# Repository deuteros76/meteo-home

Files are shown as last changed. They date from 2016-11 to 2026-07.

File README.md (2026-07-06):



# meteo-home
MeteoHome was born as a weather station project using a NodeMCU ESP8266 devboard with DHT22 and BMP180 sensors. Now, the concept has changed and the board (currently a Wemos D1 Lite) and the source are being redesigned to allow the use of different type of sensors. One of the main features of MeteoHome is the configuration using a captive web portal and the use of MQTT to send the information to a server. Additionally, it has been designed to be connected to a machine running Home Assistant. In this case, this software could be used to show the current status of the sensors and display graphs.

## Features
- configuration of WiFi network and MQTT through a web portal 
- Deep sleep mode included for being powered by battery 
- Temperature, humidity, air pressure and air quality measurements depending on the sensors plugged to the board ( currently DHT22, BMP180, SGP30 or AHT20)
- Support for analog sensors (moisture, proximity) with configurable value mapping
- Enhanced captive portal with improved UI and grouped settings panels
- Possibility of being used with Home Assistant

### Supported Sensors
MeteoHome supports multiple sensor types that can be used simultaneously:

- DHT22: Temperature (°C) and humidity (%) measurements
- BMP180: Temperature (°C) and atmospheric pressure (Pa)
- SGP30: Air quality monitoring with CO2 (ppm) and VOC (ppb) measurements
- AHT20: High-precision temperature (°C) and humidity (%) readings
- Analog Sensors: Configurable for moisture (%) or proximity (mm) measurements through A0 pin

### LED Indicators
The board includes three status LEDs. These LEDs provide visual feedback during boot sequence and runtime operation:

During boot:

- All LEDs flash once during initial power-up
- Green LED indicates successful boot and connection

During operation with SGP30 air quality monitoring:

- Green LED: Indicates good air quality (CO2 < 600 ppm)
- Yellow LED: Indicates moderate air quality (CO2 600-800 ppm)
- Red LED: Indicates poor air quality (CO2 > 800 ppm)

## Future
The idea is to continue the development of both hardware and software. Currently the MCU is a Wemos D1 Lite but the plan is to extend the possibilities including an ESP32 or a Raspberry Pi Pico, At the same time, the software will accept more sensors and will be adapted to the new hardware.

- Integration of light sensor
- ~~Integration of ATH20 sensor~~
- Adoption of a new MCU (ESP32 or Raspberry Pi Pico)
- Hardware redesign for the new MCU
- Development of software for the new board 

## Requirements
- PlatformIO IDE (used to build, test and check quality of code)
- Additional libraries: WiFiManager, Arduino Json, PubSubClient, DHT, Adafruit BMP085 and Adafruit AHTX0 (see platformio.ini)
- A computer running MQTT
- [Optional] A computer running Home Assistant

## Building the software

To build the software PlatformIO is needed. There are two options, the first one is to use the IDE and the second, covered here, is to use the pio command:

```shell
pio run --environment d1_mini_lite
```

## Hardware

The hardware has been designed in Kicad. All the source files are available under the Kicad directory of this repository.

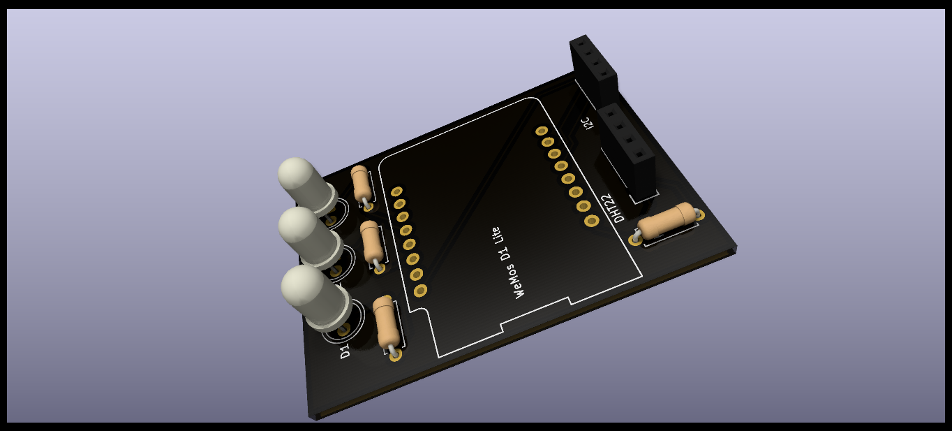
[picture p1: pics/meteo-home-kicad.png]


### Hardware components
- Wemos D1 Mini Lite (the board is designed to use this microcontroller)
- One or more sensors (DHT22, BMP180, SGP-30)
- Analog sensors (moisture, proximity sensors connected to A0 pin)
- Wires, tools...

Below the current BOM is shown. There are no sensors included, as the idea is to plug any of the supported and are not considered part of the hardware design:

|#  |Reference|Qty|Value |LibPart |Footprint|
|---|---|---|---|---|----|
|1  |A1 |1  |Analog Sensor |Connector:Conn_01x03_Socket |Connector_PinSocket_2.54mm:PinSocket_1x03_P2.54mm_Vertical|
|2  |D1 |1  |Red |meteo-home-rescue:LED-meteo-home-rescue-co2-detector-rescue |LED_THT:LED_D3.0mm|
|3  |D2 |1  |Yellow |meteo-home-rescue:LED-meteo-home-rescue-co2-detector-rescue |LED_THT:LED_D3.0mm|
|4  |D3 |1  |Green |meteo-home-rescue:LED-meteo-home-rescue-co2-detector-rescue |LED_THT:LED_D3.0mm|
|5  |DHT22 |1  |DHT22_Temperature_Humidity|meteo-home-rescue:DHT22_Temperature_Humidity-sensors-meteo-home-rescue-co2-detector-rescue|Sensors:DHT22_Temperature_Humidity|
|6  |I2C1 |1  |I2C 1 |Connector:Conn_01x04_Socket |Connector_PinSocket_2.54mm:PinSocket_1x04_P2.54mm_Vertical|
|7  |I2C2 |1  |I2C 2 |Connector:Conn_01x04_Socket |Connector_PinSocket_2.54mm:PinSocket_1x04_P2.54mm_Vertical|
|8  |I2C3 |1  |I2C 3 |Connector:Conn_01x04_Socket |Connector_PinSocket_1.00mm:PinSocket_1x04_P1.00mm_Vertical|
|9  |I2C4 |1  |I2C 4 |Connector:Conn_01x04_Socket |Connector_PinSocket_1.00mm:PinSocket_1x04_P1.00mm_Vertical|
|10 |J1 |1  |S 4 |Connector:Conn_01x04_Socket |Connector_PinSocket_2.54mm:PinSocket_1x04_P2.54mm_Vertical|
|11 |MCU1 |1  |WeMos_D1_mini |meteo-home-rescue:WeMos_D1_mini-wemos_mini-meteo-home-rescue-co2-detector-rescue|Module:WEMOS_D1_mini_light|
|12 |PWR1 |1  |Power connector |Connector:Conn_01x02_Socket |Connector_Molex:Molex_SL_171971-0002_1x02_P2.54mm_Vertical|
|13 |R1, R2 |2  |160 |meteo-home-rescue:R-meteo-home-rescue-co2-detector-rescue  |Resistor_THT:R_Axial_DIN0204_L3.6mm_D1.6mm_P5.08mm_Horizontal|
|14 |R3 |1  |90 |meteo-home-rescue:R-meteo-home-rescue-co2-detector-rescue  |Resistor_THT:R_Axial_DIN0204_L3.6mm_D1.6mm_P5.08mm_Horizontal|
|15 |R4 |1  |10K |meteo-home-rescue:R-meteo-home-rescue-co2-detector-rescue  |Resistor_THT:R_Axial_DIN0204_L3.6mm_D1.6mm_P5.08mm_Horizontal|
|16 |Tx1 |1  |Rx |Connector:Conn_01x02_Socket |Connector_PinSocket_2.54mm:PinSocket_1x02_P2.54mm_Vertical|

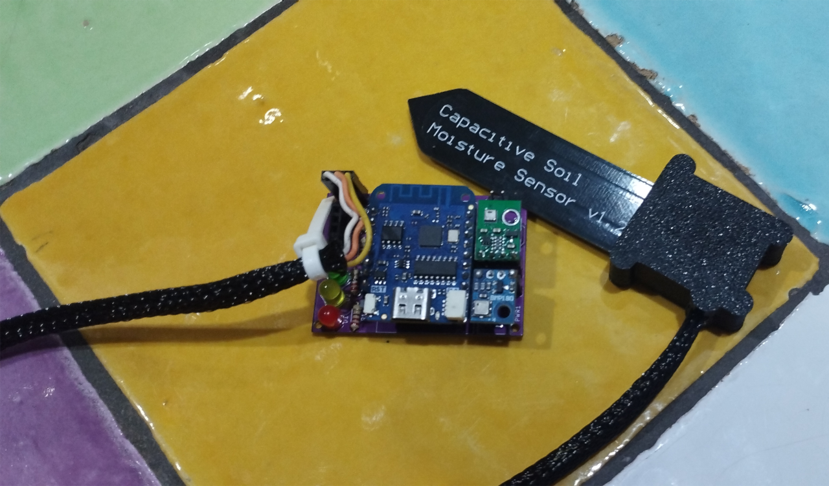
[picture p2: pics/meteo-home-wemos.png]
Real hardware
 

## Configuring a meteo-home device
After uploading the sketch and the first execution the device will run as an Access Point. Check the available networks for you computer and connect with "meteo-home". After that, point your browser to http://192.168.4.1 and the captive portal will be displayed. 

> **Note:** on some Android phones, the system's captive-portal-login popup can show a stale or incomplete cached version of the page (e.g. missing the "Network settings"/"MQTT Server settings"/"Device parameters" fields on the "Configure WiFi" page). If that happens, open a regular browser (Chrome, Firefox, etc.) and navigate to http://192.168.4.1 manually instead of using the auto-launched popup.

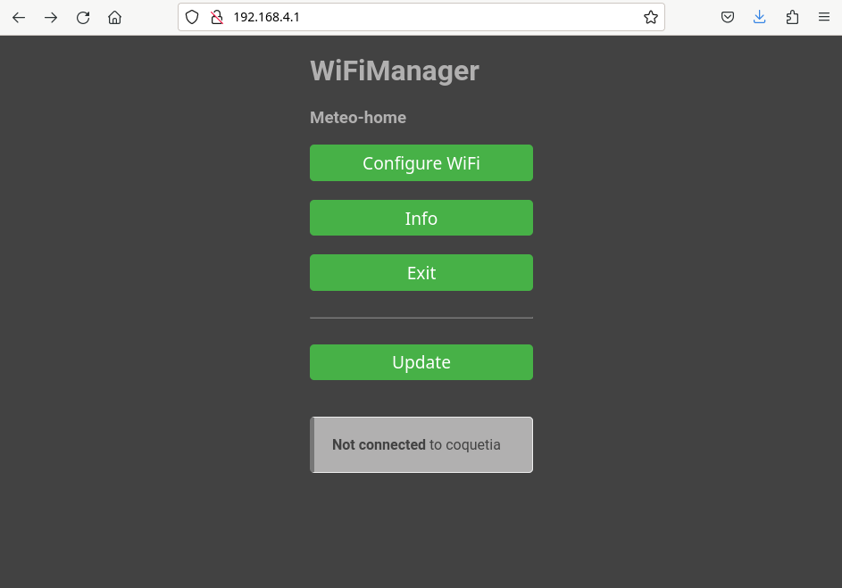
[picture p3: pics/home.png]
Home
 

Choose the first option ("Configure WiFi") and select your home WiFi network from the list of detected APs and introduce its password. 

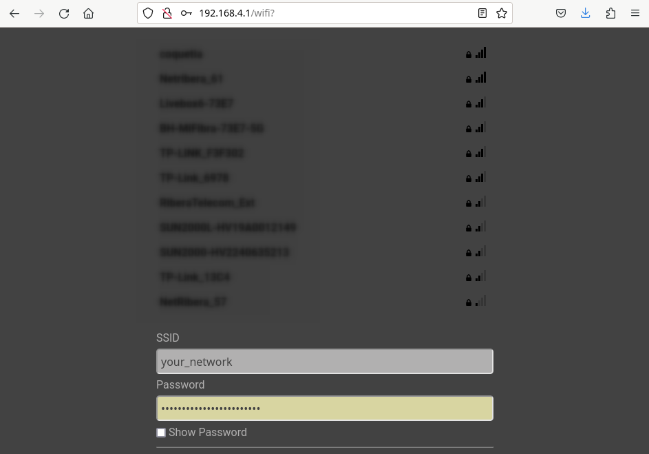
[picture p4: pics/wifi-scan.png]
Available networks
 

Now you have to configure your network settings. Below, the fields related to your MQTT server should be introduced. Then, in the "Device parameters" section, it is required to introduce a word identifying your device (you can use a name or the location where it will be installed). This value will be used to create the topics where the data will be sent through MQTT. 

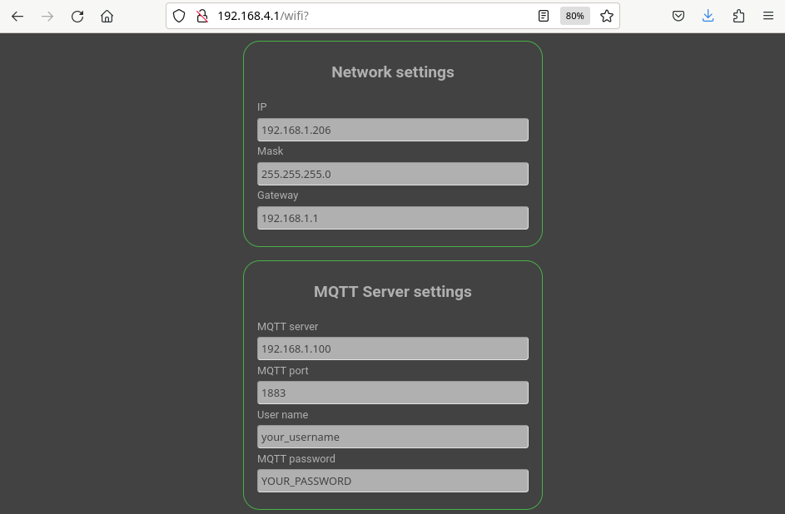
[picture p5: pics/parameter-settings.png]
Settings
 

The device supports analog sensors connected to the A0 pin. Through the captive portal, you can:

- Enable/disable analog sensor reading
- Select sensor class (moisture or proximity)
- Configure value mapping between raw analog readings (0-1024) to percentage (0-100%)
- Set minimum and maximum thresholds for the mapping function

Settings 

The improved captive portal now features:

- Grouped settings panels for better organization
- Dynamic show/hide of configuration options
- Real-time value preview using range sliders
- Enhanced visual styling and layout

## Remote reconfiguration

Once configured, a MeteoHome device can be reconfigured without physical access by
publishing an MQTT command. Only device/sensor parameters can be changed (not network or
MQTT credentials, which still require deleting `config.json` and going through the portal
again).

Each device has a secret 32-character token (`config_token`), generated automatically. On a
new device it is shown on the captive portal page, next to the device name. On a device
updated from a firmware version prior to this feature, the token is generated on the first
boot after the update and printed once over Serial (9600 baud) — check it before it's lost,
or delete `config.json` to go through the portal again and see it there.

To reconfigure, publish a JSON with `retain=true` to `meteohome/<device>/config/set`,
including the token and only the fields you want to change:

```shell
mosquitto_pub -h <broker> -t 'meteohome/attic/config/set' -r \
  -m '{"token":"<config_token>","sleep_minutes":10,"device_name":"attic"}'
```

Accepted fields: `device_name`, `use_sleep_mode`, `sleep_minutes` (1-60),
`use_analog_sensor`, `sensor_class`, `use_arduino_map_function`, `analog_min_value` and
`analog_max_value` (0-1024, with `analog_min_value < analog_max_value`).

The device responds on `meteohome/<device>/config/result` (not retained):

- `{"status":"applied","fields":[...]}` — change applied; the device restarts.
- `{"status":"error","reason":"invalid_token"}` — token missing or incorrect.
- `{"status":"error","reason":"invalid_payload"}` — malformed JSON.
- `{"status":"error","reason":"invalid_field:<name>"}` — a field is out of range or of the
  wrong type; no change is applied (transactional validation).

After processing the command (whether successful or not), the device clears the retained
message on `config/set` so it isn't reprocessed on the next reconnection.

In addition, on every connection to the broker the device publishes its current
configuration (without the token) as retained on `meteohome/<device>/config/state`:

```json
{
  "device_name": "attic",
  "use_sleep_mode": true,
  "sleep_minutes": 15,
  "use_analog_sensor": false,
  "sensor_class": "moisture",
  "use_arduino_map_function": true,
  "analog_min_value": 0,
  "analog_max_value": 1024
}
```

This topic makes it possible to build a form (for example, in Home Assistant) that
auto-fills with the device's real values before sending a change.

### Remote reconfiguration page

`tools/remote-config.html` is a self-contained page (HTML + JS, no backend or external
dependencies) that reads a device's state and applies changes without hand-crafting JSON.
Open it directly as a local file in your browser (double-click or `file://`).

**Prerequisite (one-time, on your broker):** enable a WebSocket listener. In Mosquitto, add
to the configuration:

```
listener 9001
protocol websockets
```

and restart the service. Without this, the page won't be able to connect.

**Usage:**
1. Open `tools/remote-config.html` in your browser.
2. Under "Broker connection", enter your broker's host and WebSocket port (the `9001` from
   the example above), and the MQTT username/password if your broker requires them. Click
   "Connect".
3. Under "Device", enter the device's `device_name` and its token, and click "Read current
   state" — the form will fill in with the device's real values.
4. Edit whichever fields you want to change and click "Apply changes". The device will
   apply the change (or return an error) and the result will appear in the "Result"
   section.

Connection details and each device's token are saved in the browser's `localStorage` where
you open the page, so you don't have to re-enter them every time — the same level of trust
you already assume by storing those same credentials elsewhere (e.g. Home Assistant). If you
expose the broker's WebSocket listener beyond your local network, do so at your own security
discretion; this page adds no extra protection on top of the existing token.

## Using MeteoHome with Home Assistant
A MeteoHome device publishes the data it collects to a MQTT broker. The topics used follow the specifications made by Home Assistant project and it is possible to use this software to store and use MeteoHome produced data. When a MeteoHome board is connected to a power source, it sends Home Assisant autodiscovery messages making it available through the MQTT integration.

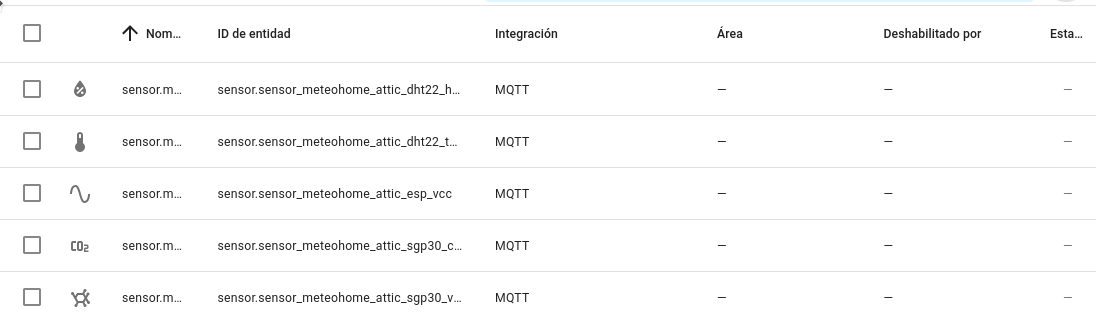
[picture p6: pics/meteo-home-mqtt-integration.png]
Home Assistant MQTT integration
 

If Home Assistant is not your preferred option, any other software that includes a MQTT broker could be used to obtain the data. To get the data, the software should be configured to subscribe to the appropriate topics. As an example the following topics are availabe if a DHT22 and SGP-30 sensors are plugged to a board configured with "attic" as topic prefix:

| Sensor  | Topic  | | | |
|---|---|---|---|---|
| DHT22  | attic/DHT22/temperature  | DHT22 temperature value  | | |
| DHT22  | attic/DHT22/humidity  | DHT22 humidity value  | | |
| DHT22  | attic/DHT22/heatindex  | DHT22 heat index value  | | |
| SGP30  | attic/SGP30/co2  | SGP30 CO2 ppp  | | |
| SGP30  | attic/SGP30/voc  | SGP30 air quality | | |
| ESP8266  | attic/ESP/vcc  | ESP8266/microcontroller voltage | | |
| Analog  | attic/moisture/value | Moisture sensor percentage |
| Analog  | attic/proximity/value | Proximity sensor value |
| AHT20 | attic/AHT20/temperature | AHT20 temperature value |
| AHT20 | attic/AHT20/humidity | AHT20 humidity value |

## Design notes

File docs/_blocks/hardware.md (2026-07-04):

---
layout: page
title: Hardware
---
The hardware has been designed in Kicad. All the source files are available under the Kicad directory of this repository.

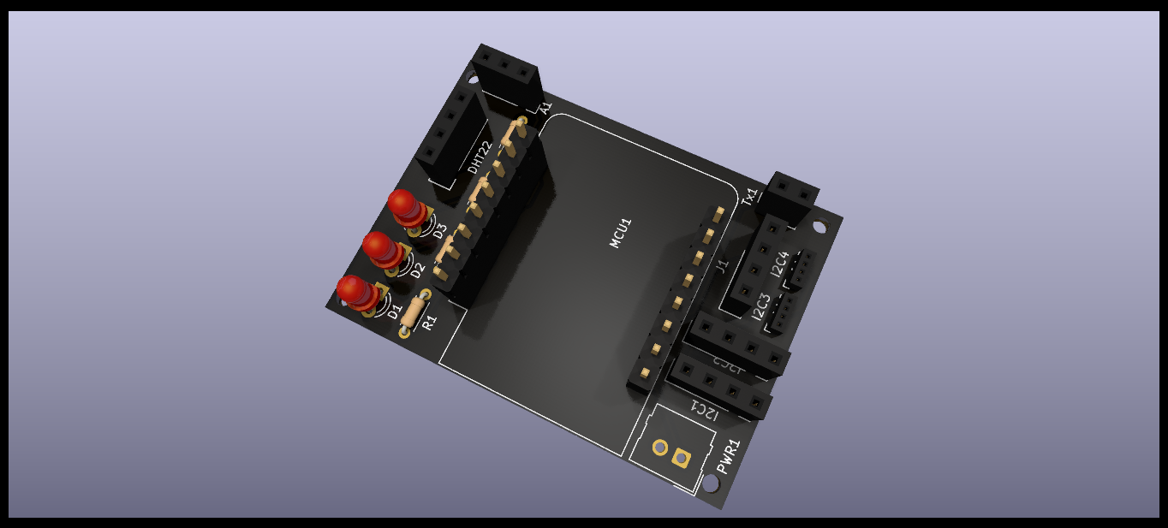
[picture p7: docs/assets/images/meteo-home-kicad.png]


### Hardware components
- {:  .list} Wemos D1 Mini Lite (the board is designed to use this microcontroller)
- {:  .list} One or more sensors (DHT22, BMPP180, SGP-30)
- {:  .list} Wires, tools...

Below the current BOM is shown. There are no sensors included, as the idea is to plug any of the supported and are not considered part of the hardware design:

|#  |Reference|Qty|Value |Footprint |
|---|---|---|---|---|
|1  |D1 |1  |Red |LEDs:LED_D5.0mm |
|2  |D2 |1  |Yellow |LEDs:LED_D5.0mm |
|3  |D3 |1  |Green |LEDs:LED_D5.0mm |
|4  |R1, R2 |2  |160 |Resistors_THT:R_Axial_DIN0207_L6.3mm_D2.5mm_P7.62mm_Horizontal|
|5  |R3 |1  |90 |Resistors_THT:R_Axial_DIN0207_L6.3mm_D2.5mm_P7.62mm_Horizontal|
|6  |R4 |1  |10K |Resistors_THT:R_Axial_DIN0207_L6.3mm_D2.5mm_P7.62mm_Horizontal|
|8  |U1 |1  |WeMos_D1_mini |wemos-d1-mini:wemos-d1-mini-with-pin-header |

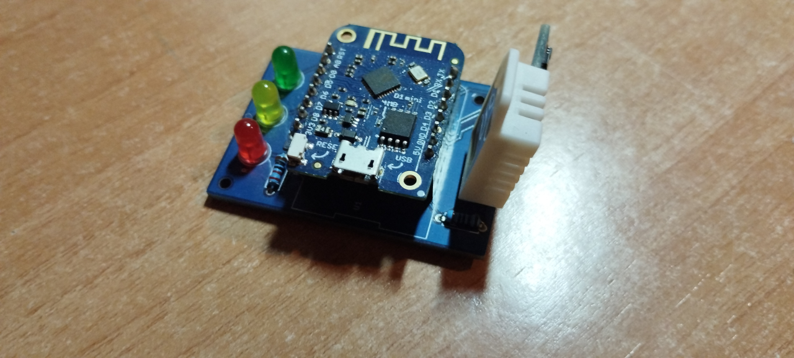
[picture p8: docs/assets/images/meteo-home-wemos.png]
Real hardware


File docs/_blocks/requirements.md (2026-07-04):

---
layout: page
title: Requirements
---
- {:  .list} PlatformIO IDE (used to build, test and check quality of code)
- {:  .list} Additional libraries: WiFiManager, Arduino Json, PubSubClient, DHT and Adafruit BMP085 (see platformio.ini)
- {:  .list} A computer running MQTT
- {:  .list} [Optional] A computer running Home Assistant

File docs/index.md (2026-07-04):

---
layout: default
---



# meteo-home
MeteoHome was born as a weather station project using a NodeMCU ESP8266 devboard with DHT22 and BMPP180 sensors. Now, the concept has changed and the board (currently a Wemos D1 Lite) and the source are being redesigned to allow the use of different type of sensors. One of the main features of MeteoHome is the configuration using a captive web portal and the use of MQTT to send the information to a server. Additionally, it has been designed to be connected to a machine running Home Assistant. In this case, this software could be used to show the current status of the sensors and display graphs.

## Features
- configuration of WiFi network and MQTT through a web portal
- Deep sleep mode included for being powered by battery
- Temperature, humidity, air pressure and air quality measurements depending on the sensors plugged to the board ( currently DHT22, BMP180 or SGP30)
- Possibility of being used with Home Assistant

## Future
The idea is to continue the development of both hardware and software. Currently the MCU is a Wemos D1 Lite but the plan is to extend the possibilites including an ESP32 or a Raspberry Pi Pico, At the same time, the sofware will accept more sensors and will be adapted to the new hardware.

- Integration of light sensor
- Integration of ATH20 sensor
- Adoption of a new MCU (ESP32 or Raspberry Pi Pico)
- Hardware redesign for the new MCU
- Development of software for the new board

## Requirements
- PlatformIO IDE (used to build, test and check quality of code)
- Additional libraries: WiFiManager, Arduino Json, PubSubClient, DHT and Adafruit BMP085 (see platformio.ini)
- A computer running MQTT
- [Optional] A computer running Home Assistant

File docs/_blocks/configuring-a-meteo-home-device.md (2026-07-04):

---
layout: page
title: Configuring a meteo-home device
---
After uploading the sketch and the first execution the device will run as an Access Point. Check the available networks for you computer and connect with "meteo-home". After that, point your browser to http://192.168.4.1 and the captive portal will be displayed. 

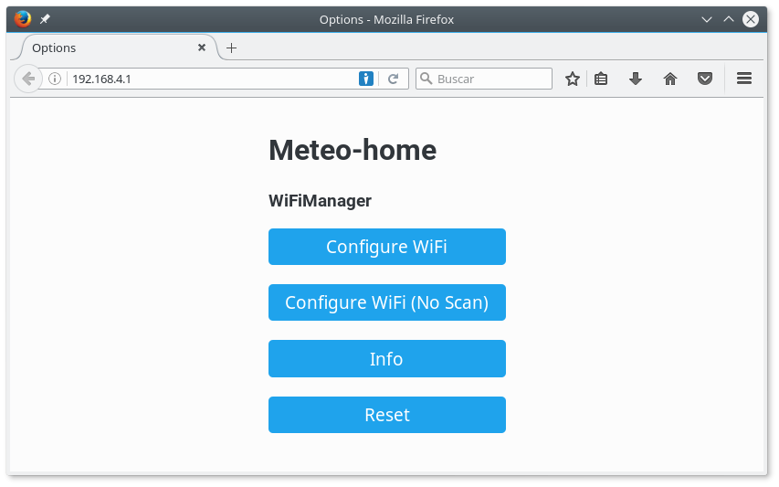
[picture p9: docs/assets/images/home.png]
Home
 

Choose the first option ("Configure WiFi") and select your home WiFi network from the list of detected APs and introduce its password. 

Available networks 

Now you have to configure your network settings. Below, the fields related to your MQTT server should be introduced. Then, in the "Device parameters" section, it is required to introduce a word identifying your device (you can use a name or the location where it will be installed). This value will be used to create the topics where the data will be sent through MQTT. 

Settings

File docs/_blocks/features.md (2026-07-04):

---
layout: page
title: Features
---
- {:  .list} configuration of WiFi network and MQTT through a web portal
- {:  .list} Deep sleep mode included for being powered by battery
- {:  .list} Temperature, humidity, air pressure and air quality measurements depending on the sensors plugged to the board ( currently DHT22, BMP180 or SGP30)
- {:  .list} Possibility of being used with Home Assistant

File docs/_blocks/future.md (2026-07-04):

---
layout: page
title: Future
---
The idea is to continue the development of both hardware and software. Currently the MCU is a Wemos D1 Lite but the plan is to extend the possibilites including an ESP32 or a Raspberry Pi Pico, At the same time, the sofware will accept more sensors and will be adapted to the new hardware.

- {:  .list} Integration of light sensor
- {:  .list} Integration of ATH20 sensor
- {:  .list} Adoption of a new MCU (ESP32 or Raspberry Pi Pico)
- {:  .list} Hardware redesign for the new MCU
- {:  .list} Development of software for the new board

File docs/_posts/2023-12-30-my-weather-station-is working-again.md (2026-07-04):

---
layout: post
title:  "My weather station is working again"
date:   2023-12-30 09:00:00 +0100
categories: meteo-home
image: /assets/images/has-meteohome-weather-ext.png
---

Following the resolution of certain power source challenges stemming from the batteries initially employed, I am happy to say that my external solar-powered weather station has been successfully restored to full functionality. This particular (MeteoHome based) weather station is equipped with a  DHT22 sensor to get both temperature and humidity levels. Additionally, it features a BMP180 sensor,  dedicated to monitoring atmospheric pressure with quite good accuracy.

The story of this gadget is that I had it working continuously for a long time, approximately two years, until [it stopped working](/es/130-recuperando-mi-metehome), and I wasn't very clear why. It spent another few years forgotten, and recently I took the opportunity to move the components to a [MeteoHome](https://github.com/deuteros76/meteo-home) PCB. Everything was working until I left it on the terrace with the solar panel, and during the night, it stopped working.

Clearly, something was happening with the recharge process. One of the problems I had was that the battery charge controller seemed to be malfunctioning. This puzzled me until I discovered that it was probably the USB cable that wasn't working because it was likely severed. Once this was resolved, I realized that, this time, I had placed rechargeable AA batteries in the same controller, which was intended for 18650 batteries.

Connecting a battery charger designed for 18650 batteries to AA batteries is not recommended and can be dangerous. 18650 and AA batteries are different types and have different electrical characteristics. In summary, they have different voltages and capacities. 18650 batteries typically have a nominal voltage of 3.7 V, while AA batteries have a voltage of 1.5 V. Additionally, their energy storage capacities also differ. Connecting a charger designed for the voltage and capacity of one type of battery to another can cause overcharging, overheating, and damage to the batteries. If you connect a 18650 battery charger to AA batteries, the charging current may be too high for the AA batteries, resulting in excessive heat, damage, overcharging, short circuits, or even the release of hazardous gases, as in the case of lithium-ion batteries.

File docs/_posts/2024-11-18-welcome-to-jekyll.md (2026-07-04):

---
layout: post
title:  "Welcome to Jekyll!"
date:   2024-11-18 09:47:47 +0100
categories: jekyll update
---

You’ll find this post in your `_posts` directory. Go ahead and edit it and re-build the site to see your changes. You can rebuild the site in many different ways, but the most common way is to run `jekyll serve`, which launches a web server and auto-regenerates your site when a file is updated.

Jekyll requires blog post files to be named according to the following format:

`YEAR-MONTH-DAY-title.MARKUP`

Where `YEAR` is a four-digit number, `MONTH` and `DAY` are both two-digit numbers, and `MARKUP` is the file extension representing the format used in the file. After that, include the necessary front matter. Take a look at the source for this post to get an idea about how it works.

Jekyll also offers powerful support for code snippets:

{% highlight ruby %}
def print_hi(name)
  puts "Hi, #{name}"
end
print_hi('Tom')
#=> prints 'Hi, Tom' to STDOUT.
{% endhighlight %}

Check out the [Jekyll docs][jekyll-docs] for more info on how to get the most out of Jekyll. File all bugs/feature requests at [Jekyll’s GitHub repo][jekyll-gh]. If you have questions, you can ask them on [Jekyll Talk][jekyll-talk].

[jekyll-docs]: https://jekyllrb.com/docs/home
[jekyll-gh]:   https://github.com/jekyll/jekyll
[jekyll-talk]: https://talk.jekyllrb.com/

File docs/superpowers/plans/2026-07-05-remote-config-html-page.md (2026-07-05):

# Página HTML de reconfiguración remota Implementation Plan

> **For agentic workers:** REQUIRED SUB-SKILL: Use superpowers:subagent-driven-development (recommended) or superpowers:executing-plans to implement this plan task-by-task. Steps use checkbox (`- [ ]`) syntax for tracking.

**Goal:** Sustituir la plantilla de Home Assistant por una única página HTML autocontenida
(`tools/remote-config.html`) que lee el estado real de un dispositivo MeteoHome vía MQTT sobre
WebSockets y permite aplicar cambios de configuración sin componer JSON a mano.

**Architecture:** Un solo archivo HTML con CSS y JavaScript inline, con la librería MQTT.js
vendorizada dentro del propio archivo (sin `.js` externo ni CDN). Se conecta directamente al
broker desde el navegador; no hay backend ni dependencia de Home Assistant. El README pierde la
sección de plantilla de HA y gana instrucciones de uso de esta página.

**Tech Stack:** HTML5, CSS, JavaScript vanilla (sin framework), MQTT.js 5.15.1 (build de
navegador, vendorizada inline), Markdown (README).

## Global Constraints

- Archivo único: `tools/remote-config.html`. Nada de `.js` externo, nada de referencias a CDN.
- Librería vendorizada: `mqtt@5.15.1`, extraída de `package/dist/mqtt.min.js` dentro del
  tarball de `npm pack mqtt@5.15.1` (confirmado: expone la variable global `mqtt`, pasa
  `node --check`, ~369.000 bytes).
- Campos del formulario y del payload de `config/set`, en este orden: `device_name`,
  `use_sleep_mode`, `sleep_minutes`, `use_analog_sensor`, `sensor_class`,
  `use_arduino_map_function`, `analog_min_value`, `analog_max_value`. El payload de aplicar
  siempre incluye `token` + los 8 campos actuales del formulario (envío atómico, no parcial).
- Tópicos: `meteohome/<device>/config/state` (leer, suscripción), `meteohome/<device>/config/set`
  (escribir, publicación retenida), `meteohome/<device>/config/result` (leer resultado,
  suscripción) — mismos nombres ya usados por el firmware, sin cambios de protocolo.
- Claves de `localStorage`: `meteohome_remote_config_connection` (JSON con `host`, `port`,
  `wss`, `user`, `password`) y `meteohome_remote_config_token_<device_name>` (token en texto
  plano, uno por nombre de dispositivo usado).
- Sin test automatizado real: se verifica sintaxis JS con `node --check` sobre el contenido de
  los `<script>` extraído, y estructura HTML con `html.parser` de Python. La verificación
  interactiva end-to-end contra un broker y un dispositivo reales queda para el usuario
  (mismo criterio ya usado para el resto de piezas MQTT de este proyecto).
- El README pierde la sección `### Formulario en Home Assistant` (helpers/automatizaciones/
  script/tarjeta) y gana instrucciones de uso de `tools/remote-config.html`, incluyendo el
  requisito previo del listener WebSocket del broker. La documentación de
  `config/set`/`config/state`/`config/result` y el ejemplo de `mosquitto_pub` no cambian.

---

### Task 1: Esqueleto de la página, MQTT.js vendorizada y panel de conexión

**Files:**
- Create: `tools/remote-config.html`

**Interfaces:**
- Consumes: nada (primer archivo del feature).
- Produces: variable global `mqtt` (de la librería vendorizada, usada por `mqtt.connect(...)`
  en este y los siguientes tasks); elementos DOM con los `id` usados en este task
  (`broker-host`, `broker-port`, `broker-wss`, `broker-user`, `broker-password`, `connect-btn`,
  `connection-status`); función `connect()` y objeto `els` (Task 2 y 3 lo extienden).

- [ ] **Step 1: Escribir el esqueleto de la página**

  Crea `tools/remote-config.html` con este contenido exacto:

  ```html
  <!DOCTYPE html>
  <!--
  Copyright 2023 meteo-home

  Licensed under the Apache License, Version 2.0 (the "License");
  you may not use this file except in compliance with the License.
  You may obtain a copy of the License at

      http://www.apache.org/licenses/LICENSE-2.0

  Unless required by applicable law or agreed to in writing, software
  distributed under the License is distributed on an "AS IS" BASIS,
  WITHOUT WARRANTIES OR CONDITIONS OF ANY KIND, either express or implied.
  See the License for the specific language governing permissions and
  limitations under the License.
  -->
  <html lang="es">
  <head>
  <meta charset="UTF-8">
  <meta name="viewport" content="width=device-width, initial-scale=1">
  <title>MeteoHome - Reconfiguración remota</title>
  <style>
    body { font-family: sans-serif; max-width: 600px; margin: 2rem auto; padding: 0 1rem; }
    section { border: 1px solid #ccc; border-radius: 8px; padding: 1rem; margin-bottom: 1.5rem; }
    label { display: block; margin-bottom: 0.75rem; }
    input[type="text"], input[type="password"], input[type="number"] { width: 100%; box-sizing: border-box; padding: 0.3rem; margin-top: 0.2rem; }
    button { padding: 0.5rem 1rem; margin-top: 0.5rem; cursor: pointer; }
    pre { white-space: pre-wrap; word-break: break-word; background: #f5f5f5; padding: 0.5rem; border-radius: 4px; }
  </style>
  </head>
  <body>
  <h1>MeteoHome &mdash; Reconfiguraci&oacute;n remota</h1>

  <section id="connection-section">
    <h2>1. Conexi&oacute;n al broker</h2>
    <label>Host
      <input id="broker-host" type="text" placeholder="192.168.1.100">
    </label>
    <label>Puerto (WebSocket)
      <input id="broker-port" type="number" value="9001">
    </label>
    <label>
      <input id="broker-wss" type="checkbox"> Usar WSS (TLS)
    </label>
    <label>Usuario MQTT
      <input id="broker-user" type="text">
    </label>
    <label>Contrase&ntilde;a MQTT
      <input id="broker-password" type="password">
    </label>
    <button id="connect-btn" type="button">Conectar</button>
    <p id="connection-status">Desconectado</p>
  </section>

  <script>
  // MQTT_JS_VENDORED_LIBRARY_PLACEHOLDER
  </script>
  <script>
  (function () {
    'use strict';

    var client = null;

    var STORAGE_CONNECTION_KEY = 'meteohome_remote_config_connection';

    var els = {
      host: document.getElementById('broker-host'),
      port: document.getElementById('broker-port'),
      wss: document.getElementById('broker-wss'),
      user: document.getElementById('broker-user'),
      password: document.getElementById('broker-password'),
      connectBtn: document.getElementById('connect-btn'),
      connectionStatus: document.getElementById('connection-status')
    };

    function setConnectionStatus(text) {
      els.connectionStatus.textContent = text;
    }

    function loadConnectionSettings() {
      var raw = localStorage.getItem(STORAGE_CONNECTION_KEY);
      if (!raw) return;
      var saved = JSON.parse(raw);
      els.host.value = saved.host || '';
      els.port.value = saved.port || 9001;
      els.wss.checked = !!saved.wss;
      els.user.value = saved.user || '';
      els.password.value = saved.password || '';
    }

    function saveConnectionSettings() {
      localStorage.setItem(STORAGE_CONNECTION_KEY, JSON.stringify({
        host: els.host.value,
        port: els.port.value,
        wss: els.wss.checked,
        user: els.user.value,
        password: els.password.value
      }));
    }

    function connect() {
      if (client) {
        client.end(true);
        client = null;
      }

      var protocol = els.wss.checked ? 'wss' : 'ws';
      var url = protocol + '://' + els.host.value + ':' + els.port.value;

      setConnectionStatus('Conectando...');

      client = mqtt.connect(url, {
        username: els.user.value || undefined,
        password: els.password.value || undefined,
        connectTimeout: 8000,
        reconnectPeriod: 0
      });

      client.on('connect', function () {
        setConnectionStatus('Conectado a ' + url);
        saveConnectionSettings();
      });

      client.on('error', function (err) {
        setConnectionStatus('Error de conexión: ' + err.message);
      });

      client.on('close', function () {
        setConnectionStatus('Desconectado');
      });
    }

    els.connectBtn.addEventListener('click', connect);

    loadConnectionSettings();
  })();
  </script>
  </body>
  </html>
  ```

- [ ] **Step 2: Vendorizar MQTT.js**

  Descarga la librería y extrae el build de navegador:

  ```bash
  mkdir -p /tmp/meteo-mqtt-vendor
  cd /tmp/meteo-mqtt-vendor
  npm pack mqtt@5.15.1 --silent
  tar xzf mqtt-5.15.1.tgz package/dist/mqtt.min.js
  cd - > /dev/null
  ls -la /tmp/meteo-mqtt-vendor/package/dist/mqtt.min.js
  ```

  Expected: un archivo de alrededor de 369.000 bytes. Si `npm pack mqtt@5.15.1` falla (p. ej.
  sin acceso a red), reporta BLOCKED indicando el error exacto — no sustituyas por una versión
  distinta sin confirmarlo.

  Inserta el contenido descargado en el marcador del HTML:

  ```bash
  node -e "
  const fs = require('fs');
  const htmlPath = 'tools/remote-config.html';
  const libPath = '/tmp/meteo-mqtt-vendor/package/dist/mqtt.min.js';
  let html = fs.readFileSync(htmlPath, 'utf8');
  const lib = fs.readFileSync(libPath, 'utf8');
  const marker = '// MQTT_JS_VENDORED_LIBRARY_PLACEHOLDER';
  if (!html.includes(marker)) { throw new Error('marker not found in ' + htmlPath); }
  html = html.replace(marker, lib);
  fs.writeFileSync(htmlPath, html);
  console.log('inlined', lib.length, 'bytes');
  "
  grep -c "MQTT_JS_VENDORED_LIBRARY_PLACEHOLDER" tools/remote-config.html
  ```

  Expected: el `node -e` imprime `inlined 369xxx bytes` y el `grep -c` devuelve `0` (marcador
  ya no existe).

- [ ] **Step 3: Verificar sintaxis JS y estructura HTML**

  ```bash
  TMPJS=$(mktemp /tmp/remote-config-extracted-XXXXXX.js)
  node -e "
  const fs = require('fs');
  const html = fs.readFileSync('tools/remote-config.html', 'utf8');
  const scripts = [...html.matchAll(/<script>([\s\S]*?)<\/script>/g)].map(m => m[1]).join('\n;\n');
  fs.writeFileSync(process.argv[1], scripts);
  " "$TMPJS"
  node --check "$TMPJS"
  echo "JS_SYNTAX_OK"
  ```

  Expected: `JS_SYNTAX_OK` sin errores de `node --check`.

  ```bash
  python3 -c "
  import html.parser
  class Checker(html.parser.HTMLParser):
      pass
  with open('tools/remote-config.html', encoding='utf-8') as f:
      content = f.read()
  Checker().feed(content)
  print('HTML_PARSE_OK')
  "
  ```

  Expected: `HTML_PARSE_OK` sin excepciones.

  Si tienes acceso a un navegador gráfico, abre el archivo, introduce cualquier host/puerto
  (p. ej. `localhost` / `1`, un puerto que seguro no responde) y pulsa "Conectar": el texto de
  estado debe cambiar a "Conectando..." y después a un mensaje de error. Si no tienes navegador
  gráfico disponible en este entorno, indícalo en el informe — la verificación interactiva
  completa contra un broker real queda para el usuario.

- [ ] **Step 4: Commit**

  ```bash
  git add tools/remote-config.html
  git commit -m "feat: add remote-config HTML page skeleton with MQTT.js and connection panel"
  ```

---

### Task 2: Sección de dispositivo, lectura de config/state y formulario

**Files:**
- Modify: `tools/remote-config.html`

**Interfaces:**
- Consumes: objeto `els`, función `setConnectionStatus`, variable `client`, función `connect()`
  (Task 1).
- Produces: elementos DOM `device-name`, `device-token`, `read-state-btn`, `read-state-status`,
  `field-device_name`, `field-use_sleep_mode`, `field-sleep_minutes`, `field-use_analog_sensor`,
  `field-sensor_class`, `field-use_arduino_map_function`, `field-analog_min_value`,
  `field-analog_max_value`; funciones `setReadStateStatus(text)`, `loadTokenForDevice(deviceName)`,
  `populateForm(state)`, `subscribeToDevice(deviceName)`, `readState()`; variables `currentDevice`,
  `readStateTimer`; función `onMessage(topic, payloadBuffer)` (Task 3 la extiende con la rama de
  `config/result`).

- [ ] **Step 1: Insertar el HTML de dispositivo y formulario**

  En `tools/remote-config.html`, usa el Edit tool con:

  old_string:
  ```html
    <button id="connect-btn" type="button">Conectar</button>
    <p id="connection-status">Desconectado</p>
  </section>

  <script>
  ```

  new_string:
  ```html
    <button id="connect-btn" type="button">Conectar</button>
    <p id="connection-status">Desconectado</p>
  </section>

  <section id="device-section">
    <h2>2. Dispositivo</h2>
    <label>Nombre del dispositivo
      <input id="device-name" type="text">
    </label>
    <label>Token
      <input id="device-token" type="password">
    </label>
    <button id="read-state-btn" type="button">Leer estado actual</button>
    
  </section>

  <section id="form-section">
    <h2>3. Configuraci&oacute;n</h2>
    <label>Nombre del dispositivo (device_name)
      <input id="field-device_name" type="text" maxlength="40">
    </label>
    <label>
      <input id="field-use_sleep_mode" type="checkbox"> Modo sleep (use_sleep_mode)
    </label>
    <label>Minutos de sleep, 1-60 (sleep_minutes)
      <input id="field-sleep_minutes" type="number" min="1" max="60">
    </label>
    <label>
      <input id="field-use_analog_sensor" type="checkbox"> Sensor anal&oacute;gico (use_analog_sensor)
    </label>
    <label>Clase de sensor (sensor_class)
      <input id="field-sensor_class" type="text" maxlength="20">
    </label>
    <label>
      <input id="field-use_arduino_map_function" type="checkbox"> Usar map() (use_arduino_map_function)
    </label>
    <label>Valor m&iacute;nimo anal&oacute;gico, 0-1024 (analog_min_value)
      <input id="field-analog_min_value" type="number" min="0" max="1024">
    </label>
    <label>Valor m&aacute;ximo anal&oacute;gico, 0-1024 (analog_max_value)
      <input id="field-analog_max_value" type="number" min="0" max="1024">
    </label>
  </section>

  <script>
  ```

- [ ] **Step 2: Añadir variables de estado del dispositivo**

  old_string:
  ```js
  (function () {
    'use strict';

    var client = null;

    var STORAGE_CONNECTION_KEY = 'meteohome_remote_config_connection';

    var els = {
  ```

  new_string:
  ```js
  (function () {
    'use strict';

    var client = null;
    var currentDevice = null;
    var readStateTimer = null;

    var STORAGE_CONNECTION_KEY = 'meteohome_remote_config_connection';
    var STORAGE_TOKEN_PREFIX = 'meteohome_remote_config_token_';
    var READ_STATE_TIMEOUT_MS = 5000;

    var els = {
  ```

- [ ] **Step 3: Extender el objeto `els` con los nuevos elementos**

  old_string:
  ```js
      connectBtn: document.getElementById('connect-btn'),
      connectionStatus: document.getElementById('connection-status')
    };
  ```

  new_string:
  ```js
      connectBtn: document.getElementById('connect-btn'),
      connectionStatus: document.getElementById('connection-status'),

      deviceName: document.getElementById('device-name'),
      deviceToken: document.getElementById('device-token'),
      readStateBtn: document.getElementById('read-state-btn'),
      readStateStatus: document.getElementById('read-state-status'),

      fieldDeviceName: document.getElementById('field-device_name'),
      fieldUseSleepMode: document.getElementById('field-use_sleep_mode'),
      fieldSleepMinutes: document.getElementById('field-sleep_minutes'),
      fieldUseAnalogSensor: document.getElementById('field-use_analog_sensor'),
      fieldSensorClass: document.getElementById('field-sensor_class'),
      fieldUseArduinoMapFunction: document.getElementById('field-use_arduino_map_function'),
      fieldAnalogMinValue: document.getElementById('field-analog_min_value'),
      fieldAnalogMaxValue: document.getElementById('field-analog_max_value')
    };
  ```

- [ ] **Step 4: Añadir `setReadStateStatus`**

  old_string:
  ```js
    function setConnectionStatus(text) {
      els.connectionStatus.textContent = text;
    }

    function loadConnectionSettings() {
  ```

  new_string:
  ```js
    function setConnectionStatus(text) {
      els.connectionStatus.textContent = text;
    }

    function setReadStateStatus(text) {
      els.readStateStatus.textContent = text;
    }

    function loadConnectionSettings() {
  ```

- [ ] **Step 5: Añadir `loadTokenForDevice`, `populateForm` y `onMessage`**

  old_string:
  ```js
    function saveConnectionSettings() {
      localStorage.setItem(STORAGE_CONNECTION_KEY, JSON.stringify({
        host: els.host.value,
        port: els.port.value,
        wss: els.wss.checked,
        user: els.user.value,
        password: els.password.value
      }));
    }

    function connect() {
  ```

  new_string:
  ```js
    function saveConnectionSettings() {
      localStorage.setItem(STORAGE_CONNECTION_KEY, JSON.stringify({
        host: els.host.value,
        port: els.port.value,
        wss: els.wss.checked,
        user: els.user.value,
        password: els.password.value
      }));
    }

    function loadTokenForDevice(deviceName) {
      var token = localStorage.getItem(STORAGE_TOKEN_PREFIX + deviceName);
      if (token) {
        els.deviceToken.value = token;
      }
    }

    function populateForm(state) {
      els.fieldDeviceName.value = state.device_name || '';
      els.fieldUseSleepMode.checked = !!state.use_sleep_mode;
      els.fieldSleepMinutes.value = state.sleep_minutes;
      els.fieldUseAnalogSensor.checked = !!state.use_analog_sensor;
      els.fieldSensorClass.value = state.sensor_class || '';
      els.fieldUseArduinoMapFunction.checked = !!state.use_arduino_map_function;
      els.fieldAnalogMinValue.value = state.analog_min_value;
      els.fieldAnalogMaxValue.value = state.analog_max_value;
    }

    function onMessage(topic, payloadBuffer) {
      if (!currentDevice) return;
      var payload = payloadBuffer.toString();

      if (topic === 'meteohome/' + currentDevice + '/config/state') {
        if (readStateTimer) {
          clearTimeout(readStateTimer);
          readStateTimer = null;
        }
        if (payload.length === 0) {
          setReadStateStatus('El dispositivo no tiene estado retenido todavía.');
          return;
        }
        populateForm(JSON.parse(payload));
        setReadStateStatus('Estado leído correctamente.');
      }
    }

    function connect() {
  ```

- [ ] **Step 6: Suscribir a los mensajes MQTT y añadir `subscribeToDevice`/`readState`**

  old_string:
  ```js
      client.on('close', function () {
        setConnectionStatus('Desconectado');
      });
    }

    els.connectBtn.addEventListener('click', connect);

    loadConnectionSettings();
  })();
  ```

  new_string:
  ```js
      client.on('close', function () {
        setConnectionStatus('Desconectado');
      });

      client.on('message', onMessage);
    }

    function subscribeToDevice(deviceName) {
      if (currentDevice && currentDevice !== deviceName) {
        client.unsubscribe('meteohome/' + currentDevice + '/config/state');
        client.unsubscribe('meteohome/' + currentDevice + '/config/result');
      }
      currentDevice = deviceName;
      client.subscribe('meteohome/' + deviceName + '/config/state');
      client.subscribe('meteohome/' + deviceName + '/config/result');
    }

    function readState() {
      if (!client || !client.connected) {
        setReadStateStatus('Conecta primero al broker.');
        return;
      }
      var deviceName = els.deviceName.value.trim();
      if (!deviceName) {
        setReadStateStatus('Introduce el nombre del dispositivo.');
        return;
      }

      loadTokenForDevice(deviceName);
      subscribeToDevice(deviceName);

      setReadStateStatus('Esperando estado del dispositivo...');

      if (readStateTimer) clearTimeout(readStateTimer);
      readStateTimer = setTimeout(function () {
        setReadStateStatus('No se ha recibido estado del dispositivo. Comprueba el nombre y que esté conectado a MQTT.');
      }, READ_STATE_TIMEOUT_MS);
    }

    els.connectBtn.addEventListener('click', connect);
    els.readStateBtn.addEventListener('click', readState);
    els.deviceName.addEventListener('change', function () {
      loadTokenForDevice(els.deviceName.value.trim());
    });

    loadConnectionSettings();
  })();
  ```

- [ ] **Step 7: Verificar sintaxis JS y estructura HTML**

  Repite exactamente los dos comandos de verificación del Task 1 Step 3 (extracción +
  `node --check`, y el chequeo con `html.parser`). Expected: `JS_SYNTAX_OK` y `HTML_PARSE_OK`
  en ambos casos, sin errores.

- [ ] **Step 8: Commit**

  ```bash
  git add tools/remote-config.html
  git commit -m "feat: add device section, config/state read-back and config form"
  ```

---

### Task 3: Aplicar cambios, resultado y persistencia del token por dispositivo

**Files:**
- Modify: `tools/remote-config.html`

**Interfaces:**
- Consumes: objeto `els`, funciones `setReadStateStatus`, `subscribeToDevice`,
  `loadTokenForDevice`, `onMessage`, variable `currentDevice` (Task 2).
- Produces: elementos DOM `apply-btn`, `result-output`; funciones `saveTokenForDevice(deviceName,
  token)`, `showResult(result)`, `applyConfig()`. Ningún task posterior consume estos símbolos
  (última pieza del feature).

- [ ] **Step 1: Insertar el botón "Aplicar" y la sección de resultado**

  old_string:
  ```html
    <label>Valor m&aacute;ximo anal&oacute;gico, 0-1024 (analog_max_value)
      <input id="field-analog_max_value" type="number" min="0" max="1024">
    </label>
  </section>

  <script>
  ```

  new_string:
  ```html
    <label>Valor m&aacute;ximo anal&oacute;gico, 0-1024 (analog_max_value)
      <input id="field-analog_max_value" type="number" min="0" max="1024">
    </label>
    <button id="apply-btn" type="button">Aplicar cambios</button>
  </section>

  <section id="result-section">
    <h2>Resultado</h2>
    <pre id="result-output">(sin resultados todav&iacute;a)</pre>
  </section>

  <script>
  ```

- [ ] **Step 2: Extender el objeto `els`**

  old_string:
  ```js
      fieldAnalogMinValue: document.getElementById('field-analog_min_value'),
      fieldAnalogMaxValue: document.getElementById('field-analog_max_value')
    };
  ```

  new_string:
  ```js
      fieldAnalogMinValue: document.getElementById('field-analog_min_value'),
      fieldAnalogMaxValue: document.getElementById('field-analog_max_value'),
      applyBtn: document.getElementById('apply-btn'),

      resultOutput: document.getElementById('result-output')
    };
  ```

- [ ] **Step 3: Añadir `saveTokenForDevice`**

  old_string:
  ```js
    function loadTokenForDevice(deviceName) {
      var token = localStorage.getItem(STORAGE_TOKEN_PREFIX + deviceName);
      if (token) {
        els.deviceToken.value = token;
      }
    }
  ```

  new_string:
  ```js
    function loadTokenForDevice(deviceName) {
      var token = localStorage.getItem(STORAGE_TOKEN_PREFIX + deviceName);
      if (token) {
        els.deviceToken.value = token;
      }
    }

    function saveTokenForDevice(deviceName, token) {
      if (!deviceName || !token) return;
      localStorage.setItem(STORAGE_TOKEN_PREFIX + deviceName, token);
    }
  ```

- [ ] **Step 4: Extender `onMessage` con la rama de `config/result` y añadir `showResult`**

  old_string:
  ```js
        populateForm(JSON.parse(payload));
        setReadStateStatus('Estado leído correctamente.');
      }
    }

    function connect() {
  ```

  new_string:
  ```js
        populateForm(JSON.parse(payload));
        setReadStateStatus('Estado leído correctamente.');
      } else if (topic === 'meteohome/' + currentDevice + '/config/result') {
        if (payload.length === 0) return;
        showResult(JSON.parse(payload));
      }
    }

    function showResult(result) {
      els.resultOutput.textContent = JSON.stringify(result, null, 2);
    }

    function connect() {
  ```

- [ ] **Step 5: Añadir `applyConfig`**

  old_string:
  ```js
      if (readStateTimer) clearTimeout(readStateTimer);
      readStateTimer = setTimeout(function () {
        setReadStateStatus('No se ha recibido estado del dispositivo. Comprueba el nombre y que esté conectado a MQTT.');
      }, READ_STATE_TIMEOUT_MS);
    }

    els.connectBtn.addEventListener('click', connect);
    els.readStateBtn.addEventListener('click', readState);
    els.deviceName.addEventListener('change', function () {
      loadTokenForDevice(els.deviceName.value.trim());
    });

    loadConnectionSettings();
  })();
  ```

  new_string:
  ```js
      if (readStateTimer) clearTimeout(readStateTimer);
      readStateTimer = setTimeout(function () {
        setReadStateStatus('No se ha recibido estado del dispositivo. Comprueba el nombre y que esté conectado a MQTT.');
      }, READ_STATE_TIMEOUT_MS);
    }

    function applyConfig() {
      if (!client || !client.connected) {
        setReadStateStatus('Conecta primero al broker.');
        return;
      }
      var deviceName = els.deviceName.value.trim();
      if (!deviceName) {
        setReadStateStatus('Introduce el nombre del dispositivo.');
        return;
      }
      var token = els.deviceToken.value.trim();
      if (!token) {
        setReadStateStatus('Introduce el token del dispositivo.');
        return;
      }

      if (currentDevice !== deviceName) {
        subscribeToDevice(deviceName);
      }

      saveTokenForDevice(deviceName, token);

      var payload = {
        token: token,
        device_name: els.fieldDeviceName.value,
        use_sleep_mode: els.fieldUseSleepMode.checked,
        sleep_minutes: parseInt(els.fieldSleepMinutes.value, 10),
        use_analog_sensor: els.fieldUseAnalogSensor.checked,
        sensor_class: els.fieldSensorClass.value,
        use_arduino_map_function: els.fieldUseArduinoMapFunction.checked,
        analog_min_value: parseInt(els.fieldAnalogMinValue.value, 10),
        analog_max_value: parseInt(els.fieldAnalogMaxValue.value, 10)
      };

      client.publish('meteohome/' + deviceName + '/config/set', JSON.stringify(payload), { retain: true });
      els.resultOutput.textContent = 'Comando enviado. Si el dispositivo está en deep-sleep, se procesará en su próximo ciclo de conexión.';
    }

    els.connectBtn.addEventListener('click', connect);
    els.readStateBtn.addEventListener('click', readState);
    els.applyBtn.addEventListener('click', applyConfig);
    els.deviceName.addEventListener('change', function () {
      loadTokenForDevice(els.deviceName.value.trim());
    });

    loadConnectionSettings();
  })();
  ```

- [ ] **Step 6: Verificar sintaxis JS y estructura HTML**

  Repite exactamente los dos comandos de verificación del Task 1 Step 3. Expected:
  `JS_SYNTAX_OK` y `HTML_PARSE_OK`, sin errores.

- [ ] **Step 7: Commit**

  ```bash
  git add tools/remote-config.html
  git commit -m "feat: add apply/result flow and per-device token persistence"
  ```

---

### Task 4: Documentación — sustituir la plantilla de Home Assistant en el README

**Files:**
- Modify: `README.md`

**Interfaces:**
- Consumes: `tools/remote-config.html` (Tasks 1-3), tópicos ya documentados
  `config/set`/`config/state`/`config/result`.
- Produces: ninguno (tarea de documentación).

- [ ] **Step 1: Confirmar los límites exactos de la sección a sustituir**

  ```bash
  grep -n "^### Formulario en Home Assistant$" README.md
  grep -n "^## Using MeteoHome with Home Assistant$" README.md
  ```

  Anota los dos números de línea (a fecha de escribir este plan son 183 y 341; si difieren,
  usa los valores reales que devuelva el `grep`). La sección a sustituir va desde la primera
  línea (inclusive) hasta la línea inmediatamente anterior a la segunda coincidencia
  (inclusive; será una línea en blanco).

- [ ] **Step 2: Sustituir la sección**

  Usa el número de línea inicial (`N1`, la línea de `### Formulario en Home Assistant`) y el
  número de línea final (`N2`, la línea en blanco justo antes de
  `## Using MeteoHome with Home Assistant`) obtenidos en el Step 1. Borra ese rango:

  ```bash
  sed -i "${N1},${N2}d" README.md
  ```

  Sustituye `${N1}` y `${N2}` por los números reales antes de ejecutar (p. ej.
  `sed -i '183,340d' README.md` si el Step 1 confirmó esos valores).

  Verifica que el borrado dejó el archivo en el punto correcto:

  ```bash
  sed -n "$((N1-3)),$((N1+1))p" README.md
  ```

  Expected: las últimas líneas del párrafo anterior ("Este tópico permite construir un
  formulario...") seguidas directamente de `## Using MeteoHome with Home Assistant`.

  Ahora inserta el contenido nuevo con el Edit tool, anclando en el mismo punto:

  old_string:
  ```markdown
  Este tópico permite construir un formulario (por ejemplo, en Home Assistant) que se
  autorrellena con los valores reales del dispositivo antes de enviar un cambio.

  ## Using MeteoHome with Home Assistant
  ```

  new_string:
  ```markdown
  Este tópico permite construir un formulario (por ejemplo, en Home Assistant) que se
  autorrellena con los valores reales del dispositivo antes de enviar un cambio.

  ### Página de reconfiguración remota

  En `tools/remote-config.html` hay una página autocontenida (HTML + JS, sin backend ni
  dependencias externas) que lee el estado de un dispositivo y aplica cambios sin componer
  JSON a mano. Se abre directamente como archivo local en el navegador (doble clic o
  `file://`).

  **Requisito previo (una sola vez, en tu broker):** habilitar un listener WebSocket. En
  Mosquitto, añade a la configuración:

  ```
  listener 9001
  protocol websockets
  ```

  y reinicia el servicio. Sin esto, la página no podrá conectar.

  **Uso:**
  1. Abre `tools/remote-config.html` en el navegador.
  2. En "Conexión al broker", introduce el host y el puerto WebSocket de tu broker (el `9001`
     del ejemplo anterior), y el usuario/contraseña MQTT si tu broker los requiere. Pulsa
     "Conectar".
  3. En "Dispositivo", introduce el `device_name` del dispositivo y su token, y pulsa "Leer
     estado actual" — el formulario se rellenará con los valores reales del dispositivo.
  4. Edita los campos que quieras cambiar y pulsa "Aplicar cambios". El dispositivo aplicará
     el cambio (o devolverá un error) y el resultado aparecerá en la sección "Resultado".

  Los datos de conexión y el token de cada dispositivo se guardan en el `localStorage` del
  navegador donde abras la página, para no tener que reintroducirlos cada vez — igual nivel de
  confianza que ya asumías guardando esas mismas credenciales en otro sitio (p. ej. Home
  Assistant). Si expones el listener WebSocket del broker más allá de tu red local, hazlo bajo
  tu propio criterio de seguridad; esta página no añade ninguna protección adicional sobre el
  token ya existente.

  ## Using MeteoHome with Home Assistant
  ```

- [ ] **Step 3: Revisión visual**

  ```bash
  grep -n "^##\|^###" README.md
  ```

  Expected: ya no aparece `### Formulario en Home Assistant`; sí aparece
  `### Página de reconfiguración remota` entre `## Reconfiguración remota` y
  `## Using MeteoHome with Home Assistant`.

- [ ] **Step 4: Commit**

  ```bash
  git add README.md
  git commit -m "docs: replace Home Assistant template with remote-config HTML page instructions"
  ```

- [ ] **Step 5: Checklist de verificación manual para el usuario (incluir en el informe final)**

  Esta página no tiene test automatizado real (ver Global Constraints). Incluye literalmente
  este checklist en el informe final para que el controlador se lo traslade al usuario:

  - [ ] Habilitar el listener WebSocket en el broker (ver README).
  - [ ] Abrir `tools/remote-config.html`, conectar con host/puerto/credenciales reales.
  - [ ] Conectar con credenciales incorrectas y confirmar que se muestra un error.
  - [ ] Con un dispositivo real (o un `mosquitto_pub -r` simulando `config/state`), pulsar
        "Leer estado actual" y confirmar que el formulario se rellena.
  - [ ] Pulsar "Leer estado actual" con un nombre de dispositivo inexistente y confirmar el
        mensaje de timeout tras ~5s.
  - [ ] Aplicar un cambio válido contra un dispositivo real y confirmar que llega el resultado
        `applied` con los campos esperados.
  - [ ] Aplicar un cambio con token incorrecto y confirmar que llega `invalid_token`.
  - [ ] Recargar la página y confirmar que los datos de conexión y el token del dispositivo
        siguen rellenos (persistencia en `localStorage`).

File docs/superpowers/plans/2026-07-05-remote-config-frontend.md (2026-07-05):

# Frontend de reconfiguración remota (Home Assistant) Implementation Plan

> **For agentic workers:** REQUIRED SUB-SKILL: Use superpowers:subagent-driven-development (recommended) or superpowers:executing-plans to implement this plan task-by-task. Steps use checkbox (`- [ ]`) syntax for tracking.

**Goal:** Añadir un tópico MQTT retenido (`config/state`) donde el dispositivo publica su
configuración actual, y documentar una plantilla de Home Assistant (helpers + automatizaciones
+ script + tarjeta) que use ese estado para ofrecer un formulario de reconfiguración remota sin
componer JSON a mano.

**Architecture:** `Manager` gana un método puro `buildConfigStatePayload()` que serializa los 7
campos reconfigurables (sin token) a JSON con tipos nativos. `MeteoBoard::connectToMQTT()`
publica ese payload como retenido en `meteohome/<device>/config/state` en cada conexión, usando
streaming (`beginPublish`/`print`/`endPublish`) para no depender del tamaño de búfer de
`PubSubClient`. El lado de Home Assistant no toca el repo de firmware: se documenta como
plantilla YAML en el README.

**Tech Stack:** ESP8266/Arduino, ArduinoJson v6.21.x, PubSubClient, PlatformIO/Unity
(`d1_mini_lite`), Home Assistant (YAML: helpers, automations, scripts, Lovelace).

## Global Constraints

- Campos incluidos en `config/state`, en este orden: `device_name`, `use_sleep_mode`,
  `sleep_minutes`, `use_analog_sensor`, `sensor_class`, `use_arduino_map_function`,
  `analog_min_value`, `analog_max_value`. El campo `token`/`config_token` **nunca** se incluye
  en este payload.
- Tipos JSON nativos (no texto): booleanos como `true`/`false` JSON, enteros como números JSON
  — a diferencia de `persistConfig()`, que serializa todo a texto para `/config.json`.
- Tópico: `meteohome/<device_name>/config/state`, análogo a `configSetTopic()`/
  `configResultTopic()` ya existentes en `Manager`.
- Publicación **retenida** (`retain=true`), en cada conexión MQTT exitosa dentro de
  `MeteoBoard::connectToMQTT()`.
- La publicación debe usar `client->beginPublish()`/`print()`/`endPublish()` (streaming), **no**
  `client->publish()`: `MQTT_MAX_PACKET_SIZE` de `PubSubClient` es 256 bytes por defecto y no
  está sobrescrito en este proyecto; con `device_name` (máx. 40 car.) y `sensor_class` (máx. 20
  car.) cerca de sus límites, el payload puede acercarse o superar ese tamaño y `publish()`
  fallaría en silencio.
- Solo se prueba de forma automatizada la construcción del payload (`buildConfigStatePayload()`
  es una función pura). La publicación real por MQTT se verifica manualmente en hardware —
  mismo criterio que el resto del feature de reconfiguración remota (`native` sigue roto por el
  problema preexistente de `PubSubClient`/`ArduinoFake`, documentado en el spec original; se usa
  `d1_mini_lite` para todos los tests).
- Entorno de verificación de build/test en esta sesión: `pio run -e d1_mini_lite` (build) y
  `pio test -e d1_mini_lite --without-uploading --without-testing` (compilación de tests), salvo
  que haya hardware ESP8266 disponible y conectado.
- Fuera de alcance: cualquier cambio a `config/set`/`config/result`/`applyRemoteConfig`; una
  página HTML independiente; entidades MQTT discovery nativas por campo (descartadas en el
  diseño por riesgo de reinicios en cascada).

---

### Task 1: `Manager::buildConfigStatePayload()` y `configStateTopic()`

**Files:**
- Modify: `include/manager.hpp` (añadir getter `configStateTopic()` y declaración de
  `buildConfigStatePayload()`)
- Modify: `src/manager.cpp` (implementación de `buildConfigStatePayload()`)
- Modify: `test/tests/test_manager.cpp` (nuevo test)
- Modify: `test/test_run_all.cpp` (registrar el nuevo test)

**Interfaces:**
- Consumes: miembros privados existentes de `Manager` (`device_name`, `use_sleep_mode`,
  `sleep_minutes`, `use_analog_sensor`, `sensor_class`, `use_arduino_map_function`,
  `analog_min_value`, `analog_max_value`); `Manager::setDeviceName`, `setSleepMinutes`,
  `setUseSleepMode`, `setUseAnalogSensor`, `setSensorClass`, `setUseArduinoMapFunction`,
  `setAnalogMinValue`, `setAnalogMaxValue`, `persistConfigForTest()`, `setup_config_data()` (ya
  existen, ver `include/manager.hpp`).
- Produces: `String Manager::configStateTopic()` (pública, inline, igual patrón que
  `configSetTopic()`), `String Manager::buildConfigStatePayload()` (pública, declarada en el
  header junto a `applyRemoteConfig`, implementada en `manager.cpp`). Task 2 consume ambos.

- [ ] **Step 1: Escribir el test que falla**

  Abre `test/tests/test_manager.cpp`. Ya existe una función helper `makeConfiguredManager()`
  (línea ~123) que crea un `Manager` completamente configurado y con token generado — reutilízala.
  Añade este test al final del archivo:

  ```cpp
  void test_buildConfigStatePayloadExcludesTokenAndUsesNativeTypes() {
      Manager manager = makeConfiguredManager();

      String payload = manager.buildConfigStatePayload();

      DynamicJsonDocument doc(384);
      DeserializationError err = deserializeJson(doc, payload);
      TEST_ASSERT_FALSE(err);

      TEST_ASSERT_FALSE(doc.containsKey("token"));
      TEST_ASSERT_FALSE(doc.containsKey("config_token"));

      TEST_ASSERT_EQUAL_STRING("device_under_test", doc["device_name"].as<const char*>());
      TEST_ASSERT_TRUE(doc["use_sleep_mode"].is<bool>());
      TEST_ASSERT_FALSE(doc["use_sleep_mode"].as<bool>());
      TEST_ASSERT_TRUE(doc["sleep_minutes"].is<int>());
      TEST_ASSERT_EQUAL(5, doc["sleep_minutes"].as<int>());
      TEST_ASSERT_TRUE(doc["use_analog_sensor"].is<bool>());
      TEST_ASSERT_TRUE(doc["use_analog_sensor"].as<bool>());
      TEST_ASSERT_EQUAL_STRING("moisture", doc["sensor_class"].as<const char*>());
      TEST_ASSERT_TRUE(doc["use_arduino_map_function"].is<bool>());
      TEST_ASSERT_TRUE(doc["use_arduino_map_function"].as<bool>());
      TEST_ASSERT_EQUAL(0, doc["analog_min_value"].as<int>());
      TEST_ASSERT_EQUAL(1024, doc["analog_max_value"].as<int>());

      TEST_ASSERT_EQUAL(8, doc.size());
  }
  ```

  Registra el test en `test/test_run_all.cpp`, añadiendo esta línea justo después de
  `RUN_TEST(test_applyRemoteConfigEmptyDeviceName);`:

  ```cpp
  RUN_TEST(test_buildConfigStatePayloadExcludesTokenAndUsesNativeTypes);
  ```

- [ ] **Step 2: Verificar que compila y falla**

  `buildConfigStatePayload()` todavía no existe, así que esto debe fallar en compilación, no en
  ejecución. Ejecuta:

  ```bash
  pio test -e d1_mini_lite --without-uploading --without-testing
  ```

  Salida esperada: error de compilación tipo `'class Manager' has no member named
  'buildConfigStatePayload'`. Confirma que el error señala exactamente esa función antes de
  continuar.

- [ ] **Step 3: Implementar `configStateTopic()` y `buildConfigStatePayload()`**

  En `include/manager.hpp`, justo debajo de la línea 80
  (`String configResultTopic(){return "meteohome/" + device_name + "/config/result";}`), añade:

  ```cpp
  //! Topic where this device publishes its current configuration (retained), for
  //! external clients (e.g. Home Assistant) to read back before issuing a config/set command.
  String configStateTopic(){return "meteohome/" + device_name + "/config/state";}
  ```

  Justo debajo de la declaración de `applyRemoteConfig` (línea 102), añade:

  ```cpp
  //! Builds the JSON payload for config/state: the 7 remotely-configurable fields with
  //! native JSON types (not text), and no token.
  String buildConfigStatePayload();
  ```

  En `src/manager.cpp`, añade la implementación cerca de `applyRemoteConfig` (al final del
  archivo está bien):

  ```cpp
  String Manager::buildConfigStatePayload(){
    DynamicJsonDocument json(384);
    json["device_name"] = device_name;
    json["use_sleep_mode"] = use_sleep_mode;
    json["sleep_minutes"] = sleep_minutes;
    json["use_analog_sensor"] = use_analog_sensor;
    json["sensor_class"] = sensor_class;
    json["use_arduino_map_function"] = use_arduino_map_function;
    json["analog_min_value"] = analog_min_value;
    json["analog_max_value"] = analog_max_value;

    String payload;
    serializeJson(json, payload);
    return payload;
  }
  ```

- [ ] **Step 4: Verificar que el test pasa**

  ```bash
  pio test -e d1_mini_lite --without-uploading --without-testing
  ```

  Confirma que compila sin errores. Si hay hardware ESP8266 conectado, ejecuta también
  `pio test -e d1_mini_lite` y confirma que
  `test_buildConfigStatePayloadExcludesTokenAndUsesNativeTypes` pasa junto con el resto de la
  suite (sin warnings nuevos).

- [ ] **Step 5: Commit**

  ```bash
  git add include/manager.hpp src/manager.cpp test/tests/test_manager.cpp test/test_run_all.cpp
  git commit -m "feat: add Manager::buildConfigStatePayload for config/state topic"
  ```

---

### Task 2: Publicar `config/state` en cada conexión MQTT

**Files:**
- Modify: `src/meteoboard.cpp` (`connectToMQTT()`)

**Interfaces:**
- Consumes: `Manager::configStateTopic()`, `Manager::buildConfigStatePayload()` (Task 1),
  `PubSubClient::beginPublish(const char* topic, unsigned int plength, boolean retained)`,
  `PubSubClient::print(const String&)` (vía `Print::print`), `PubSubClient::endPublish()` —
  mismo patrón que `MeteoBoard::sendDiscoveryMessage()` en el mismo archivo (línea ~126).
- Produces: ningún símbolo nuevo consumido por otras tareas; este task cierra el flujo de
  firmware del plan.

- [ ] **Step 1: Localizar el punto de inserción**

  Abre `src/meteoboard.cpp` y localiza `MeteoBoard::connectToMQTT()` (línea ~70). El bloque
  relevante, dentro del `if (client->connect(...))`, termina así:

  ```cpp
    if (client->connect(clientName.c_str(), availabilityTopic.c_str(), 0, true, "offline")) {
      Serial.println("[Board] Connected to mqtt");
      client->publish(availabilityTopic.c_str(), "online", true);
      // Subscribe to Home Assistant birth topic to resend discovery on HASS restart
      client->subscribe("homeassistant/status");
      client->subscribe(manager->configSetTopic().c_str());
    } else {
  ```

- [ ] **Step 2: Añadir la publicación de estado**

  Sustituye ese bloque por (añadiendo las 6 líneas nuevas antes de `} else {`):

  ```cpp
    if (client->connect(clientName.c_str(), availabilityTopic.c_str(), 0, true, "offline")) {
      Serial.println("[Board] Connected to mqtt");
      client->publish(availabilityTopic.c_str(), "online", true);
      // Subscribe to Home Assistant birth topic to resend discovery on HASS restart
      client->subscribe("homeassistant/status");
      client->subscribe(manager->configSetTopic().c_str());

      // Publish current config as retained state, so external clients (e.g. Home
      // Assistant) can read it back before issuing a config/set command. Streamed via
      // beginPublish/print/endPublish (same pattern as sendDiscoveryMessage) because the
      // payload can approach PubSubClient's default 256-byte MQTT_MAX_PACKET_SIZE with a
      // long device_name/sensor_class, and publish() would silently fail past that limit.
      String stateTopic = manager->configStateTopic();
      String statePayload = manager->buildConfigStatePayload();
      if (client->beginPublish(stateTopic.c_str(), statePayload.length(), true)) {
        client->print(statePayload);
        client->endPublish();
      } else {
        Serial.println("[Board] Error publishing config/state");
      }
    } else {
  ```

- [ ] **Step 3: Verificar que compila**

  ```bash
  pio run -e d1_mini_lite
  ```

  Expected: `SUCCESS`.

  ```bash
  pio test -e d1_mini_lite --without-uploading --without-testing
  ```

  Expected: compila sin errores (no hay test automatizado nuevo para este paso — la
  publicación MQTT real se verifica manualmente en hardware, ver Step 4).

- [ ] **Step 4: Verificación manual en hardware (si hay un dispositivo disponible)**

  Con un ESP8266 flasheado y conectado al broker, suscríbete a
  `meteohome/<device>/config/state` (usa el `device_name` real del dispositivo, p. ej.
  `attic`):

  ```bash
  mosquitto_sub -h <broker> -t 'meteohome/attic/config/state' -v
  ```

  Al conectar el dispositivo (o al despertar de deep-sleep), debe aparecer un mensaje JSON con
  los 7 campos y **sin** `token`. Si no hay hardware disponible en esta sesión, deja constancia
  en el reporte de que este paso queda pendiente de verificación manual, igual que se hizo para
  el resto del feature de reconfiguración remota.

- [ ] **Step 5: Commit**

  ```bash
  git add src/meteoboard.cpp
  git commit -m "feat: publish retained config/state on every MQTT connection"
  ```

---

### Task 3: Documentar `config/state` y la plantilla de Home Assistant en el README

**Files:**
- Modify: `README.md` (sección "Reconfiguración remota", líneas ~128-162 en el estado actual)

**Interfaces:**
- Consumes: `config/state` (Task 2), `config/set`/`config/result` (ya documentados), los
  nombres de campo del Global Constraints de este plan.
- Produces: ninguno (tarea de documentación, no de código).

- [ ] **Step 1: Añadir la descripción del tópico `config/state`**

  En `README.md`, justo antes de la sección `## Using MeteoHome with Home Assistant` (después
  del párrafo que termina en "...para no reprocesarlo en la siguiente reconexión."), añade:

  ```markdown
  Además, en cada conexión al broker el dispositivo publica su configuración actual (sin el
  token) como retenido en `meteohome/<device>/config/state`:

  ```json
  {
    "device_name": "attic",
    "use_sleep_mode": true,
    "sleep_minutes": 15,
    "use_analog_sensor": false,
    "sensor_class": "moisture",
    "use_arduino_map_function": true,
    "analog_min_value": 0,
    "analog_max_value": 1024
  }
  ```

  Este tópico permite construir un formulario (por ejemplo, en Home Assistant) que se
  autorrellena con los valores reales del dispositivo antes de enviar un cambio.

  ### Formulario en Home Assistant

  Con `config/state` y `config/set`/`config/result` se puede montar un formulario en Home
  Assistant que lee el estado real del dispositivo y aplica cambios con un botón, sin
  componer JSON a mano. Por cada dispositivo (usando su `device_name` como identificador,
  p. ej. `attic`), añade estos helpers en Ajustes → Dispositivos y servicios → Ayudantes, o
  directamente en `configuration.yaml`:

  ```yaml
  input_text:
    meteohome_attic_device_name:
      name: "Attic - nombre"
    meteohome_attic_sensor_class:
      name: "Attic - clase de sensor"
    meteohome_attic_token:
      name: "Attic - token"
      mode: password

  input_boolean:
    meteohome_attic_use_sleep_mode:
      name: "Attic - modo sleep"
    meteohome_attic_use_analog_sensor:
      name: "Attic - sensor analógico"
    meteohome_attic_use_arduino_map_function:
      name: "Attic - usar map()"

  input_number:
    meteohome_attic_sleep_minutes:
      name: "Attic - minutos de sleep"
      min: 1
      max: 60
      step: 1
    meteohome_attic_analog_min_value:
      name: "Attic - valor mínimo analógico"
      min: 0
      max: 1024
    meteohome_attic_analog_max_value:
      name: "Attic - valor máximo analógico"
      min: 0
      max: 1024
  ```

  Automatización que mantiene los helpers sincronizados con el estado real del dispositivo:

  ```yaml
  automation:
    - alias: "MeteoHome attic - sincronizar estado"
      trigger:
        - platform: mqtt
          topic: "meteohome/attic/config/state"
      action:
        - service: input_text.set_value
          target: {entity_id: input_text.meteohome_attic_device_name}
          data: {value: "{{ trigger.payload_json.device_name }}"}
        - service: "input_boolean.turn_{{ 'on' if trigger.payload_json.use_sleep_mode else 'off' }}"
          target: {entity_id: input_boolean.meteohome_attic_use_sleep_mode}
        - service: input_number.set_value
          target: {entity_id: input_number.meteohome_attic_sleep_minutes}
          data: {value: "{{ trigger.payload_json.sleep_minutes }}"}
        - service: "input_boolean.turn_{{ 'on' if trigger.payload_json.use_analog_sensor else 'off' }}"
          target: {entity_id: input_boolean.meteohome_attic_use_analog_sensor}
        - service: input_text.set_value
          target: {entity_id: input_text.meteohome_attic_sensor_class}
          data: {value: "{{ trigger.payload_json.sensor_class }}"}
        - service: "input_boolean.turn_{{ 'on' if trigger.payload_json.use_arduino_map_function else 'off' }}"
          target: {entity_id: input_boolean.meteohome_attic_use_arduino_map_function}
        - service: input_number.set_value
          target: {entity_id: input_number.meteohome_attic_analog_min_value}
          data: {value: "{{ trigger.payload_json.analog_min_value }}"}
        - service: input_number.set_value
          target: {entity_id: input_number.meteohome_attic_analog_max_value}
          data: {value: "{{ trigger.payload_json.analog_max_value }}"}
  ```

  Script que aplica los cambios (arma el JSON con los valores actuales de los helpers y lo
  publica en `config/set`):

  ```yaml
  script:
    meteohome_attic_apply_config:
      alias: "MeteoHome attic - aplicar configuración"
      sequence:
        - service: mqtt.publish
          data:
            topic: "meteohome/attic/config/set"
            retain: true
            payload: >
              {{ {
                "token": states('input_text.meteohome_attic_token'),
                "device_name": states('input_text.meteohome_attic_device_name'),
                "use_sleep_mode": is_state('input_boolean.meteohome_attic_use_sleep_mode', 'on'),
                "sleep_minutes": states('input_number.meteohome_attic_sleep_minutes') | int,
                "use_analog_sensor": is_state('input_boolean.meteohome_attic_use_analog_sensor', 'on'),
                "sensor_class": states('input_text.meteohome_attic_sensor_class'),
                "use_arduino_map_function": is_state('input_boolean.meteohome_attic_use_arduino_map_function', 'on'),
                "analog_min_value": states('input_number.meteohome_attic_analog_min_value') | int,
                "analog_max_value": states('input_number.meteohome_attic_analog_max_value') | int
              } | tojson }}
  ```

  Tarjeta Lovelace con el formulario y el botón de aplicar:

  ```yaml
  type: entities
  title: MeteoHome - attic
  entities:
    - input_text.meteohome_attic_device_name
    - input_boolean.meteohome_attic_use_sleep_mode
    - input_number.meteohome_attic_sleep_minutes
    - input_boolean.meteohome_attic_use_analog_sensor
    - input_text.meteohome_attic_sensor_class
    - input_boolean.meteohome_attic_use_arduino_map_function
    - input_number.meteohome_attic_analog_min_value
    - input_number.meteohome_attic_analog_max_value
    - input_text.meteohome_attic_token
    - entity: script.meteohome_attic_apply_config
      name: "Aplicar cambios"
  ```

  Y una automatización que notifica el resultado en la propia UI de Home Assistant:

  ```yaml
  automation:
    - alias: "MeteoHome attic - notificar resultado"
      trigger:
        - platform: mqtt
          topic: "meteohome/attic/config/result"
      action:
        - service: persistent_notification.create
          data:
            title: "MeteoHome attic"
            message: >
              {{ 'Configuración aplicada: ' ~ trigger.payload_json.fields | join(', ')
                 if trigger.payload_json.status == 'applied'
                 else 'Error: ' ~ trigger.payload_json.reason }}
  ```

  **Notas:**
  - Repite esta plantilla por cada dispositivo, cambiando `attic` por el `device_name` real en
    los IDs de entidad y en los tópicos.
  - Si renombras un dispositivo cambiando `device_name` desde este formulario, el dispositivo
    pasa a publicar todo (estado, resultado, sensores, disponibilidad) bajo el nuevo nombre a
    partir del siguiente reinicio; actualiza el "slug" en la plantilla YAML de este dispositivo
    a mano tras el cambio.
  - `mode: password` en el helper del token solo lo oculta en la interfaz; Home Assistant lo
    guarda igual que cualquier otro estado, con el mismo nivel de confianza que ya tienen las
    credenciales MQTT de tu propio `configuration.yaml`.
  - Si tu broker no persiste mensajes retenidos en disco (p. ej. Mosquitto con
    `persistence false`), un reinicio del broker hace que se pierda el último `config/state`
    hasta que el dispositivo se reconecte en su siguiente ciclo (más notable con intervalos de
    deep-sleep largos).
  ```

- [ ] **Step 2: Revisión visual**

  Renderiza el README (o ábrelo en un visor de Markdown) y confirma que los bloques de código
  YAML/JSON no rompen el formato de las secciones adyacentes, y que el orden de secciones queda:
  "Reconfiguración remota" (con `config/set`, `config/result`, `config/state` y el formulario de
  HA) seguida de "Using MeteoHome with Home Assistant".

- [ ] **Step 3: Commit**

  ```bash
  git add README.md
  git commit -m "docs: document config/state topic and Home Assistant remote-config template"
  ```

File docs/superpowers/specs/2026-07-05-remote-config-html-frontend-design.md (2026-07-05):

# Diseño: página HTML autocontenida para reconfiguración remota

**Fecha:** 2026-07-05
**Estado:** Aprobado para planificación
**Sustituye a:** la sección "Home Assistant" de
[`2026-07-05-remote-config-frontend-design.md`](2026-07-05-remote-config-frontend-design.md)
(helpers/automatizaciones/script/tarjeta). El tópico `meteohome/<device>/config/state` y su
publicación en firmware, ya implementados según ese documento, **no cambian** y son la base de
este diseño.

## Problema

La plantilla de Home Assistant (9 helpers, una automatización de sincronización, un script y
una tarjeta Lovelace, repetido por cada dispositivo) resultó ser demasiada configuración manual
por dispositivo. Se busca una alternativa con mucho menos trabajo de configuración por
dispositivo, sin perder la posibilidad de leer el estado real antes de cambiarlo ni el envío
atómico de todos los campos a la vez.

## Alcance

Una única página HTML autocontenida, sin backend ni dependencia de Home Assistant, que hable
MQTT directamente desde el navegador vía WebSockets. Sustituye la plantilla de HA como único
método documentado en el README para la reconfiguración remota práctica (`mosquitto_pub` a mano
sigue siendo válido y queda documentado como hasta ahora, para quien lo prefiera).

Explícitamente **fuera de alcance**:
- Cualquier backend, servidor local o infraestructura de hosting: la página se abre como
  archivo local (`file://`).
- Cambios al protocolo `config/set`/`config/state`/`config/result` ya existente: se reutiliza
  tal cual.
- Configurar el listener WebSocket del broker: es un requisito previo de infraestructura del
  usuario, documentado pero no automatizable desde este repositorio.

## Requisito previo (infraestructura, fuera del repo)

El broker MQTT necesita un listener WebSocket habilitado (p. ej. en Mosquitto, añadir a su
configuración `listener 9001` y `protocol websockets`). Sin esto, la página no puede conectar.
Se documenta como paso previo en el README; no es algo que el firmware o la página puedan
resolver.

## Arquitectura

Archivo único: `tools/remote-config.html`. Contiene HTML, CSS y JavaScript, con la librería
MQTT.js (build de navegador, UMD) vendorizada **inline** dentro de una etiqueta `<script>` del
propio archivo — no hay un `.js` separado ni referencia a ningún CDN. Esto evita dos problemas:
rutas relativas que se rompen si el archivo se copia/mueve (a un móvil, un USB...), y la
dependencia de acceso a internet más allá de la red local donde está el broker.

La página no tiene build ni dependencias de instalación: se abre directamente en el navegador
como archivo local.

## Componentes de la página

- **Conexión**: host y puerto del broker, checkbox WS/WSS (TLS), usuario y contraseña MQTT.
  Botón "Conectar".
- **Dispositivo**: nombre del dispositivo y token (campo tipo contraseña). Botón "Leer estado
  actual".
- **Formulario**: los 8 campos reconfigurables — `device_name`, `use_sleep_mode`,
  `sleep_minutes`, `use_analog_sensor`, `sensor_class`, `use_arduino_map_function`,
  `analog_min_value`, `analog_max_value`.
- **Botón "Aplicar cambios"**: construye el JSON completo (token + los 8 campos del formulario
  tal cual están en ese momento) y lo publica retenido en `config/set`. Envío atómico de todos
  los campos a la vez, igual que el ejemplo de `mosquitto_pub` ya documentado — no hay
  casillas de "incluir campo".
- **Resultado**: panel que muestra la respuesta de `config/result` en cuanto llega.
- **Persistencia (`localStorage`)**: datos de conexión al broker, y por cada nombre de
  dispositivo usado, su token — para no tener que reintroducirlos en visitas posteriores.

## Flujo de datos

```
Abrir la página (archivo local) → datos de conexión → "Conectar"
                                    │
                                    ▼
Nombre de dispositivo (autorrelleno de token si ya se usó antes) → "Leer estado actual"
                                    │
                                    ▼
Suscripción a config/state (retenido) → formulario se rellena con el estado real
                                    │
                                    ▼
Editar campos → "Aplicar cambios" → publicar JSON completo retenido en config/set
                                    │
                                    ▼
Suscripción a config/result → se muestra el resultado en cuanto el dispositivo responde
```

## Manejo de errores

| Situación | Comportamiento |
|---|---|
| Fallo de conexión WebSocket (broker inalcanzable o sin listener WS) | Mensaje visible sugiriendo comprobar el listener WS del broker |
| Fallo de autenticación MQTT | Mensaje de error al conectar (evento `error` de MQTT.js) |
| Sin respuesta a "Leer estado actual" tras ~5s | "No se ha recibido estado del dispositivo. Comprueba el nombre y que esté conectado a MQTT." |
| `config/result` con `status: "error"` | Se muestra literalmente el `reason` devuelto por el firmware (`invalid_token`, `invalid_payload`, `invalid_field:<campo>`), sin reinterpretar |
| Sin respuesta a `config/set` (p. ej. dispositivo en deep-sleep) | No es un error: nota informativa de que el comando queda retenido y se procesará en el próximo ciclo de conexión del dispositivo |

## Seguridad

- El token y las credenciales MQTT quedan en `localStorage` del navegador donde se abra la
  página, en texto plano — mismo nivel de confianza que ya se asumía al guardar esas mismas
  credenciales en Home Assistant; no es una relajación de seguridad, solo cambia dónde vive el
  mismo dato bajo el control del usuario.
- La página no introduce superficie de ataque nueva: solo habla MQTT con el broker indicado,
  igual que ya hacía `mosquitto_pub` manualmente. El token del dispositivo sigue siendo el único
  mecanismo de autorización de `config/set`, sin cambios respecto al diseño original.
- El listener WebSocket del broker es un puerto adicional de acceso a MQTT. Exponerlo más allá
  de la red local (p. ej. mediante port-forwarding) es una decisión de infraestructura del
  usuario, ajena a esta página; se documentará como aviso en el README.

## Testing

Página estática sin build ni framework: no hay tests automatizados. Verificación manual
(documentada como checklist en el plan de implementación):
- Conexión correcta e incorrecta (credenciales/host erróneos).
- Lectura de `config/state` de un dispositivo real (o simulado con `mosquitto_pub -r` publicando
  un payload de estado a mano, si no hay hardware disponible en el momento de implementar).
- Aplicación de un cambio y recepción del resultado, tanto en caso de éxito como de error
  (token incorrecto, campo fuera de rango).
- Persistencia en `localStorage` tras recargar la página.

Mismo criterio de verificación manual ya usado para el resto de piezas dependientes de MQTT en
este proyecto.

## Documentación

Se actualiza `README.md`: se elimina la sección de plantilla de Home Assistant (helpers,
automatizaciones, script, tarjeta) añadida en la iteración anterior, y se sustituye por
instrucciones de uso de `tools/remote-config.html`, incluyendo el requisito previo del listener
WebSocket del broker. La documentación de `config/set`/`config/state`/`config/result` y
`mosquitto_pub` como alternativa manual se mantiene sin cambios.

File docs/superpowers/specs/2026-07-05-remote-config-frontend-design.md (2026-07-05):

# Diseño: frontend de reconfiguración remota vía Home Assistant

**Fecha:** 2026-07-05
**Estado:** Aprobado para planificación

## Problema

La funcionalidad de reconfiguración remota vía MQTT (`meteohome/<device>/config/set`,
ver [`2026-07-05-remote-config-design.md`](2026-07-05-remote-config-design.md)) solo se puede
usar hoy publicando manualmente un JSON con `mosquitto_pub`, incluyendo el token de memoria y
recordando qué campos existen y qué formato tienen. No hay una forma cómoda de reconfigurar un
dispositivo sin componer el JSON a mano, y no hay manera de conocer los valores actuales del
dispositivo antes de cambiarlos: el dispositivo no expone su configuración por MQTT, solo se
ve borrando `config.json` o en el portal cautivo.

## Alcance

Se añaden dos piezas:

1. **Firmware**: un nuevo tópico retenido `meteohome/<device>/config/state`, publicado por el
   dispositivo en cada conexión MQTT, con su configuración actual (los mismos 7 campos
   reconfigurables, **sin el token**).
2. **Home Assistant**: una plantilla YAML documentada (helpers + automatizaciones + script +
   tarjeta Lovelace) por dispositivo, que sincroniza un formulario con el estado real del
   dispositivo y permite aplicar cambios con un botón, sin escribir JSON a mano.

Explícitamente **fuera de alcance**:
- Una página HTML independiente o cualquier frontend fuera de Home Assistant (se descartó en
  el brainstorming: el usuario ya usa HA como panel principal y gestiona pocos dispositivos de
  forma ocasional, por lo que no compensa mantener una interfaz nueva y separada).
- Entidades nativas de HA vía MQTT discovery por campo (se descartó: el firmware reinicia el
  dispositivo tras cualquier cambio aplicado con éxito, y una entidad nativa por campo
  arriesgaría reinicios en cascada por cada ajuste individual —p. ej. al arrastrar un slider—
  en vez de un envío atómico de todos los campos a la vez).
- Cualquier cambio al protocolo `config/set` / `config/result` ya existente: se reutiliza tal
  cual.
- Rotación o visualización del `config_token` por este canal: sigue exclusivamente disponible
  por el portal cautivo o Serial, como ya establece el diseño original.

## Arquitectura

### Componentes modificados (firmware)

**`Manager`** (`manager.{hpp,cpp}`)
- Nuevo getter `configStateTopic()`: `"meteohome/" + device_name + "/config/state"`.
- Nuevo método `String buildConfigStatePayload()`: serializa los 7 campos reconfigurables
  (`device_name`, `use_sleep_mode`, `sleep_minutes`, `use_analog_sensor`, `sensor_class`,
  `use_arduino_map_function`, `analog_min_value`, `analog_max_value`) a JSON, **sin** el
  `config_token`. A diferencia de `persistConfig()` (que serializa todo como texto para
  compatibilidad con el parseo existente de `/config.json`), aquí se usan los tipos JSON
  nativos (booleanos y enteros reales), de forma que el payload de `config/state` sea
  directamente reutilizable como payload de `config/set` (añadiendo el token) sin conversión.

**`MeteoBoard`** (`meteoboard.cpp`)
- En `connectToMQTT()`, tras las suscripciones existentes, se publica el estado usando el
  patrón de streaming ya usado por `sendDiscoveryMessage()` (`beginPublish()` / `print()` /
  `endPublish()`), no `client->publish()` directo:

  ```cpp
  String stateTopic = manager->configStateTopic();
  String statePayload = manager->buildConfigStatePayload();
  if (client->beginPublish(stateTopic.c_str(), statePayload.length(), true)) {
    client->print(statePayload);
    client->endPublish();
  }
  ```

  **Motivo de usar streaming en vez de `publish()`:** `MQTT_MAX_PACKET_SIZE` de `PubSubClient`
  es 256 bytes por defecto (topic + payload + cabecera) y no está sobrescrito en este proyecto.
  Con un `device_name` largo (hasta 40 caracteres, máximo permitido por el portal) y
  `sensor_class` cerca de su máximo (20 caracteres), el payload de estado puede acercarse o
  superar ese límite, y `publish()` fallaría en silencio. El streaming de `beginPublish`/
  `print`/`endPublish` no depende del tamaño del búfer, evitando el problema sin tener que
  aumentar `MQTT_MAX_PACKET_SIZE`.
- Se publica en cada conexión MQTT exitosa (incluido cada ciclo de reconexión en modo
  deep-sleep), como retenido, para que el último estado conocido esté siempre disponible al
  suscribirse (incluido tras un reinicio de Home Assistant).

### Componente nuevo (Home Assistant, documentado en README, no en el repo de firmware)

Por cada dispositivo (usando su `device_name` como "slug", p. ej. `attic`):

- **Helpers**: `input_text` (nombre, clase de sensor, token), `input_boolean` (los 3 flags),
  `input_number` (minutos de sleep, valores mínimo/máximo analógicos) — representan el
  formulario editable.
- **Automatización de sincronización**: trigger MQTT sobre `meteohome/<device>/config/state`,
  que actualiza cada helper con el valor recibido (`input_text.set_value`,
  `input_number.set_value`, `input_boolean.turn_on`/`turn_off` según el campo booleano
  correspondiente).
- **Script "Aplicar"**: construye el JSON completo (token + 7 campos) a partir del valor
  actual de los helpers y lo publica con `mqtt.publish` (`retain: true`) en
  `meteohome/<device>/config/set`.
- **Tarjeta Lovelace**: tarjeta de entidades con los 8 campos del formulario y un botón que
  ejecuta el script.
- **Automatización de notificación de resultado**: trigger MQTT sobre
  `meteohome/<device>/config/result`, que crea una `persistent_notification` con el resultado
  (campos aplicados, o motivo del error), para que el éxito o fallo de la reconfiguración sea
  visible en la propia UI de HA sin inspeccionar MQTT directamente.

### Flujo de datos

```
Dispositivo conecta MQTT → publica config/state (retenido, sin token)
                                    │
                                    ▼
HA: automatización de sincronización → actualiza helpers con valores reales
                                    │
                                    ▼
Usuario edita helpers en la tarjeta Lovelace → pulsa "Aplicar"
                                    │
                                    ▼
HA: script → mqtt.publish a config/set (token + 7 campos, retain=true)
                                    │
                                    ▼
Dispositivo aplica cambio (o rechaza) → publica config/result
                                    │
                                    ▼
HA: automatización de notificación → persistent_notification con el resultado
                                    │
                                    ▼
Si se aplicó, el dispositivo se reinicia y, al reconectar, vuelve a publicar
config/state → HA resincroniza los helpers con el nuevo estado real
```

## Formato del payload de `config/state`

```json
{
  "device_name": "attic",
  "use_sleep_mode": true,
  "sleep_minutes": 15,
  "use_analog_sensor": false,
  "sensor_class": "moisture",
  "use_arduino_map_function": true,
  "analog_min_value": 0,
  "analog_max_value": 1024
}
```

Mismo conjunto de campos que `config/set`, sin `token`, con tipos JSON nativos (no texto).

## Seguridad

- **Token no incluido en `config/state`**: publicar el token en un tópico retenido de solo
  lectura lo expondría de forma pasiva a cualquier suscriptor sin que se emita ningún comando,
  aumentando su superficie de exposición respecto al diseño original (donde el token solo
  viaja cuando alguien lo usa activamente para reconfigurar). El usuario ya conoce su token por
  el portal/Serial, y el formulario de HA lo guarda en un `input_text` aparte, solo para
  construir el payload de `config/set`.
- **Token en Home Assistant**: `mode: password` en el `input_text` del token solo oculta el
  valor en la UI; HA lo guarda igualmente en claro en su estado interno, igual que ya ocurre
  con las credenciales MQTT del propio `configuration.yaml`. Es el mismo nivel de confianza que
  ya se asume al dar a HA acceso al broker; no es una relajación de seguridad respecto al
  diseño original del token.
- No se introduce ningún cambio en la validación, autenticación o superficie de ataque del
  canal `config/set` ya existente.

## Casos límite y comportamiento esperado

- **Renombrar un dispositivo** (`device_name`): al ser parte del tópico
  (`meteohome/<device_name>/...`), cambiarlo hace que el dispositivo publique todo bajo el
  nuevo nombre a partir del siguiente reinicio. Los helpers/automatizaciones/script de ese
  dispositivo quedan apuntando al tópico antiguo; hay que actualizar manualmente el "slug" en
  la plantilla YAML. Se documentará como nota junto a la plantilla.
- **Broker sin persistencia de mensajes retenidos**: si el broker se reinicia sin persistencia
  en disco, se pierde el último `config/state` hasta que el dispositivo se reconecte en su
  siguiente ciclo (más relevante con intervalos de deep-sleep largos). No requiere manejo
  especial.
- **`config/result` de error sin campo `fields`**: la plantilla Jinja de la notificación de
  resultado no accede a `fields` en la rama de error, solo a `reason`.
- **Varios dispositivos**: la plantilla se repite cambiando el "slug" en IDs de entidad y
  tópicos, igual que ya ocurre con las tarjetas de sensores existentes documentadas para HA.

## Testing

- **Firmware**: test unitario en `test_manager.cpp` para `buildConfigStatePayload()` — JSON
  válido, los 7 campos con tipo correcto (booleanos como `bool`, no como texto), y ausencia de
  la clave `token`. Es una función pura sin dependencia de `PubSubClient`, se ejecuta en
  `d1_mini_lite` (mismo entorno usado en el resto de tests de esta área; `native` sigue roto
  por el problema preexistente de `PubSubClient`/`ArduinoFake` documentado en el spec
  original).
- La publicación real vía streaming en `connectToMQTT()` se verifica manualmente en hardware
  (mensaje retenido visible al suscribirse a `config/state`), no hay infraestructura de test
  para esa parte.
- **Home Assistant**: la plantilla YAML no es código del repo ni tiene test automatizado; se
  verifica manualmente (aplicar un cambio desde la tarjeta, comprobar la notificación de
  resultado, comprobar que los helpers se resincronizan tras un reinicio del dispositivo o de
  Home Assistant).

## Documentación

Se actualiza `README.md`, ampliando la sección "Reconfiguración remota" con: el nuevo tópico
`config/state`, su formato, y la plantilla YAML completa de Home Assistant (helpers,
automatizaciones, script y tarjeta) con las notas sobre renombrado de dispositivos y
persistencia de retenidos.

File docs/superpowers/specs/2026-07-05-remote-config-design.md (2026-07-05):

# Diseño: reconfiguración remota segura vía MQTT

**Fecha:** 2026-07-05
**Estado:** Aprobado para planificación

## Problema

Hoy la única forma de reconfigurar un dispositivo MeteoHome ya desplegado es borrar
manualmente `/config.json` (acceso físico) para forzar que vuelva a arrancar el portal
cautivo de `WiFiManager`. No existe ninguna vía para cambiar parámetros del dispositivo sin
manipularlo físicamente.

## Alcance

Se añade un canal de reconfiguración remota vía MQTT, limitado a los parámetros de
dispositivo/sensores que **no** afectan a la conectividad de red:

- `device_name`
- `use_sleep_mode`
- `sleep_minutes`
- `use_analog_sensor`
- `sensor_class`
- `use_arduino_map_function`
- `analog_min_value`
- `analog_max_value`

Explícitamente **fuera de alcance**: red WiFi, servidor/usuario/contraseña MQTT y el propio
`config_token` no son reconfigurables por este canal. Un cambio incorrecto en esos campos
podría dejar el dispositivo inalcanzable, y seguirían requiriendo el borrado manual de
`config.json` como hoy. Rotar el token también requiere ese mismo camino (borrar
`config.json` y volver a pasar por el portal).

## Arquitectura

### Componentes modificados

**`Manager`** (`manager.{hpp,cpp}`)
- Nuevo miembro `config_token` (String), persistido en `/config.json`.
- Nuevo getter `configToken()`.
- Nuevos setters privados/internos para los ocho campos remotamente configurables listados
  arriba.
- Nuevo método `bool applyRemoteConfig(JsonDocument &doc, String &errorReason)`: valida token
  y campos, actualiza los miembros correspondientes y persiste. Devuelve `false` sin mutar
  estado si algo falla.
- Nuevo método privado `persistConfig()`: serializa **todos** los miembros actuales
  (incluido `config_token`) a `/config.json`. Sustituye al bloque de guardado actual en
  `setup_wifi()`, que hoy serializa directamente desde los `WiFiManagerParameter` en lugar de
  desde los miembros de la clase — se refactoriza para que el bloque de guardado del portal
  asigne primero a los miembros y después llame a `persistConfig()`, evitando duplicar la
  lógica de serialización entre el flujo del portal y el flujo remoto.
- Generación del token: si `config_token` no existe en `/config.json` (dispositivo nuevo o
  actualización de firmware sobre un dispositivo ya configurado), se genera con
  `secureRandom()` (RNG hardware del núcleo ESP8266, sin dependencias nuevas): 16 bytes
  aleatorios codificados en hex (32 caracteres), y se persiste inmediatamente.

**`MeteoBoard`** (`meteoboard.{hpp,cpp}`)
- `connectToMQTT()` añade una suscripción a `meteohome/<device>/config/set`, junto a la ya
  existente `homeassistant/status`.
- `mqttCallback` distingue el tópico de config del de `homeassistant/status` y delega en un
  nuevo método `handleConfigCommand(String payload)`.
- `handleConfigCommand()`:
  1. Parsea el JSON del payload.
  2. Llama a `manager->applyRemoteConfig(doc, errorReason)`.
  3. Publica el resultado en `meteohome/<device>/config/result` (no retenido).
  4. Limpia el comando publicando un mensaje vacío retenido en `config/set` (para no
     reprocesarlo en la siguiente reconexión/arranque).
  5. Si se aplicó correctamente, llama a `ESP.restart()` (mismo patrón que el guardado desde
     el portal cautivo en `Manager::setup_wifi()`).

**Portal cautivo (`manager.cpp`, `setup_wifi()`)**
- Cuando el portal se ejecuta por primera vez (dispositivo nuevo, sin `config.json`), se
  añade un `WiFiManagerParameter` de solo lectura que muestra el `config_token` recién
  generado, con una nota indicando que hay que guardar ese valor para poder reconfigurar el
  dispositivo remotamente más adelante.
- En dispositivos ya configurados que actualizan de firmware, el portal no se ejecuta (ya
  existe `config.json`), así que el token generado en ese caso solo se imprime una vez por
  Serial al arrancar. Se documentará en el README: revisar el monitor serie tras la primera
  actualización de firmware, o borrar `config.json` para volver a pasar por el portal y
  verlo ahí.

### Flujo de datos

1. Un cliente externo (Home Assistant, script, `mosquitto_pub`) publica un JSON con
   `retain=true` en `meteohome/<device>/config/set`, incluyendo el token y los campos a
   cambiar.
2. Al conectar o reconectar (incluido el ciclo breve de conexión en modo deep-sleep), el
   dispositivo recibe el mensaje retenido vía `mqttCallback`.
3. `MeteoBoard::handleConfigCommand()` procesa el payload como se describe arriba.
4. Si el token y los valores son válidos, `Manager` actualiza sus miembros y persiste; el
   dispositivo reinicia para que todo lo derivado (tópicos derivados del nombre, hostname
   OTA, temporizadores de sleep, etc.) se reinicialice de forma consistente, igual que ocurre
   hoy tras guardar desde el portal.

## Formato del payload

Actualización parcial: solo se modifican los campos presentes en el payload. `token` es
obligatorio; el resto son opcionales.

```json
{
  "token": "a1b2c3...",
  "device_name": "Attic",
  "use_sleep_mode": true,
  "sleep_minutes": 15,
  "use_analog_sensor": false,
  "sensor_class": "moisture",
  "use_arduino_map_function": true,
  "analog_min_value": 0,
  "analog_max_value": 1024
}
```

Campos no reconocidos en el payload se ignoran (se registran por Serial, no interrumpen el
procesamiento del resto).

## Seguridad

- **Autenticidad:** el bróker MQTT ya exige usuario/contraseña (capa existente). Además, todo
  comando de reconfiguración debe incluir el `config_token` del dispositivo, generado
  aleatoriamente y no editable por el usuario ni por este mismo canal. Esto evita que
  cualquier cliente autenticado en el bróker (que puede ser compartido con otros
  dispositivos/integraciones) reconfigure un MeteoHome sin conocer su token específico.
- **Comparación de token:** comparación de cadena estándar (`token == config_token`). No se
  usa comparación en tiempo constante: el canal va sobre una conexión MQTT ya autenticada por
  TCP, y no es un vector de temporización práctico en este contexto; añadir eso sería
  sobre-ingeniería para este caso de uso.
- **Superficie de ataque limitada:** el canal solo permite modificar parámetros que no
  afectan a la conectividad (ver "Alcance"). Un comando erróneo o malicioso en el peor caso
  cambia el nombre del dispositivo o el comportamiento de un sensor, nunca deja el
  dispositivo inalcanzable.
- **Sin rotación remota:** el token no puede cambiarse por este canal; rotarlo exige acceso
  físico (borrar `config.json` y repetir el portal), igual que cualquier otra
  reconfiguración de red hoy.

## Manejo de errores

Todas las validaciones son transaccionales: si un solo campo del payload falla, se rechaza
el comando completo y no se aplica ningún cambio.

| Situación | Respuesta en `config/result` | ¿Reinicia? |
|---|---|---|
| Token ausente o incorrecto | `{"status":"error","reason":"invalid_token"}` | No |
| JSON malformado | `{"status":"error","reason":"invalid_payload"}` | No |
| Campo fuera de rango/tipo inválido | `{"status":"error","reason":"invalid_field:<nombre>"}` | No |
| Todo válido | `{"status":"applied","fields":[...]}` | Sí |

Validaciones por campo:
- `sleep_minutes`: entero 1–60.
- `analog_min_value` / `analog_max_value`: enteros 0–1024, con `min < max`.
- `sensor_class` / `device_name`: no vacíos.
- Campos booleanos: deben deserializar como booleano válido.

En todos los casos (éxito o error) se limpia el tópico `config/set` publicando un mensaje
vacío retenido, para no reprocesar el mismo comando en la siguiente reconexión.

## Testing

**Nota sobre el entorno `native`:** durante la planificación se comprobó que
`pio test -e native` ya falla hoy, antes de este feature: `test/test_run_all.cpp` incluye
incondicionalmente `mhdht.hpp` → `meteosensor.hpp` → `PubSubClient.h`, y `PubSubClient.h`
requiere `IPAddress.h`/`Client.h` de un core Arduino real que `ArduinoFake` no provee.
Reparar esto exigiría añadir mocks de red a `ArduinoFake`, una tarea de infraestructura
mayor y no relacionada con esta funcionalidad. Por eso, los tests de este feature se escriben
como tests de hardware en `d1_mini_lite` (mismo patrón que ya se usa para los sensores),
y la reparación del entorno `native` queda fuera de alcance de este plan.

- `d1_mini_lite`: tests para `Manager::applyRemoteConfig()` cubriendo token
  correcto/incorrecto/ausente, cada validación de campo, actualización parcial (solo algunos
  campos presentes), y que `persistConfig()` serializa correctamente todos los miembros
  (incluido `config_token`).
- `d1_mini_lite`: tests para `MeteoBoard::handleConfigCommand()` verificando que se publica
  el resultado correcto en `config/result` y que se limpia el retained de `config/set` en
  cada caso (éxito y error).
- La generación del token vía `secureRandom()` no se testea de forma automatizada (depende
  de RNG hardware); se verifica manualmente en `d1_mini_lite` (token visible en el portal en
  un dispositivo nuevo, y por Serial en una actualización de firmware sobre un dispositivo ya
  configurado).

## Documentación

Se actualiza `README.md` con: la nueva sección de "Configuración remota", los tópicos
`config/set` / `config/result`, el formato del payload, y la nota sobre dónde encontrar el
`config_token` en cada escenario (portal para dispositivos nuevos, Serial para
actualizaciones de firmware existentes).

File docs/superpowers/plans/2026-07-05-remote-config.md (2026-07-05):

# Reconfiguración remota segura vía MQTT — Implementation Plan

> **For agentic workers:** REQUIRED SUB-SKILL: Use superpowers:subagent-driven-development (recommended) or superpowers:executing-plans to implement this plan task-by-task. Steps use checkbox (`- [ ]`) syntax for tracking.

**Goal:** Permitir reconfigurar remotamente los parámetros de dispositivo/sensores de un
MeteoHome ya desplegado (sin acceso físico) publicando un comando JSON firmado con un token
secreto en un tópico MQTT, sin tocar red/MQTT/credenciales.

**Architecture:** `Manager` gana persistencia canónica (`persistConfig()`), un token secreto
auto-generado (`config_token`), y una función pura de validación/aplicación
(`applyRemoteConfig()`). `MeteoBoard` se suscribe a un tópico de comando MQTT retenido,
delega la validación en `Manager`, publica el resultado y reinicia el dispositivo si el
cambio se aplicó. Ver el spec completo en
`docs/superpowers/specs/2026-07-05-remote-config-design.md`.

**Tech Stack:** ESP8266 Arduino core (`secureRandom()`), ArduinoJson 6.21.3
(`DynamicJsonDocument`/`JsonDocument`), PubSubClient 2.8, WiFiManager 2.0.17, LittleFS, Unity
(tests en hardware `d1_mini_lite`).

## Global Constraints

- Campos remotamente configurables: **solo** `device_name`, `use_sleep_mode`,
  `sleep_minutes`, `use_analog_sensor`, `sensor_class`, `use_arduino_map_function`,
  `analog_min_value`, `analog_max_value`. Red, MQTT y el propio `config_token` **nunca** son
  modificables por este canal.
- El token (`config_token`) se auto-genera con `secureRandom()` (16 bytes → 32 caracteres
  hex), nunca es editable por el usuario ni rotable por MQTT.
- Validación transaccional: si un solo campo del payload falla, no se aplica ningún cambio.
- El comando se publica con `retain=true`; el dispositivo limpia el retained
  (mensaje vacío retenido) tras procesarlo, tanto en éxito como en error.
- Aplicar un cambio válido siempre termina en `ESP.restart()`.
- **`pio test -e native` está roto de antes** (cadena `mhdht.hpp → meteosensor.hpp →
  PubSubClient.h → IPAddress.h`, ausente en `ArduinoFake`). No se toca en este plan. Todos
  los tests nuevos son tests de hardware en `d1_mini_lite` (mismo patrón que los tests de
  sensores existentes).
- Persistencia en disco: `persistConfig()` debe serializar `use_sleep_mode`,
  `use_analog_sensor` y `use_arduino_map_function` como las cadenas `"true"`/`"false"` (no
  booleanos JSON nativos), y `sleep_minutes`/`analog_min_value`/`analog_max_value` como
  cadenas numéricas (no números JSON nativos). Esto es obligatorio para no romper el código
  de lectura existente en `Manager::setup_config_data()`, que castea esos campos a
  `const char*` antes de parsearlos — un número o booleano JSON nativo se castea a `nullptr`
  y rompería la carga silenciosamente.

---

### Task 1: Extraer `Manager::persistConfig()` y refactorizar el guardado del portal

**Files:**
- Modify: `include/manager.hpp`
- Modify: `src/manager.cpp:44-104` (lectura), `src/manager.cpp:247-286` (guardado)
- Test: `test/tests/test_manager.cpp`
- Modify: `test/test_run_all.cpp`

**Interfaces:**
- Produces: `void Manager::persistConfig()` (privado) — serializa todos los miembros actuales
  a `/config.json`, con el formato de tipos descrito en Global Constraints.
- Produces: comportamiento observable sin cambios — `setup_wifi()` sigue guardando
  exactamente los mismos campos que antes, solo que ahora vía `persistConfig()`.

Este task es un refactor puro (sin funcionalidad nueva) para poder reutilizar la lógica de
guardado desde el flujo remoto en el Task 4, sin duplicarla. Se verifica con un test de
round-trip: guardar con `persistConfig()` y releer con `setup_config_data()` debe devolver
los mismos valores.

- [ ] **Step 1: Escribir el test de round-trip (debe fallar: `persistConfig` no existe aún)**

Añadir a `test/tests/test_manager.cpp`:

```cpp
void test_persistConfigRoundTrip() {
    LittleFS.remove("/config.json");

    DynamicJsonDocument json(1024);
    json["network_ip"] = "192.168.1.50";
    json["network_mask"] = "255.255.255.0";
    json["network_gateway"] = "192.168.1.1";
    json["mqtt_server"] = "192.168.1.100";
    json["mqtt_port"] = "1883";
    json["mqtt_user"] = "user";
    json["mqtt_password"] = "pass";
    json["use_sleep_mode"] = "true";
    json["sleep_minutes"] = "15";
    json["device_name"] = "roundtrip_device";
    json["use_analog_sensor"] = "false";
    json["sensor_class"] = "moisture";
    json["use_arduino_map_function"] = "true";
    json["analog_min_value"] = "10";
    json["analog_max_value"] = "900";
    json["config_token"] = "deadbeef";

    File configFile = LittleFS.open("/config.json", "w");
    serializeJson(json, configFile);
    configFile.close();

    Manager manager;
    manager.setup_config_data();

    // Mutate a couple of fields the same way applyRemoteConfig will, then persist.
    manager.setSleepMinutes(30);
    manager.setDeviceName("roundtrip_device_renamed");
    manager.persistConfigForTest();

    Manager reloaded;
    reloaded.setup_config_data();

    TEST_ASSERT_EQUAL_STRING("roundtrip_device_renamed", reloaded.deviceName().c_str());
    TEST_ASSERT_EQUAL(30, reloaded.sleepMinutes());
    TEST_ASSERT_TRUE(reloaded.useSleepMode());
    TEST_ASSERT_FALSE(reloaded.useAnalogSensor());
    TEST_ASSERT_EQUAL_STRING("moisture", reloaded.sensorClass().c_str());
    TEST_ASSERT_EQUAL(10, reloaded.analogMinValue());
    TEST_ASSERT_EQUAL(900, reloaded.analogMaxValue());
    TEST_ASSERT_EQUAL_STRING("deadbeef", reloaded.configToken().c_str());
}
```

> Nota: `setSleepMinutes`, `setDeviceName`, `persistConfigForTest` y `configToken` no existen
> todavía — se añaden en los pasos siguientes de este mismo task (los setters y un método
> `persistConfigForTest()` público de solo-test que llama al `persistConfig()` privado; el
> `config_token` se añade aquí directamente para que el round-trip cubra también ese campo,
> ya que Task 2 depende de que `persistConfig()` ya lo serialice).

Registrar el test en `test/test_run_all.cpp` (añadir tras `test_setupConfigData`):

```cpp
    RUN_TEST(test_persistConfigRoundTrip);
```

- [ ] **Step 2: Ejecutar los tests en hardware y confirmar que falla la compilación**

Run: `pio test -e d1_mini_lite -f test_manager`
Expected: FAIL to compile — `'class Manager' has no member named 'setSleepMinutes'` (u otro
miembro nuevo referenciado en el test).

- [ ] **Step 3: Añadir a `include/manager.hpp` los miembros y firmas nuevas**

En la sección `public:` de `Manager`, junto a los getters existentes:

```cpp
  String configToken(){return config_token;}

  // Setters usados por el flujo de reconfiguración remota (Task 4) y por este test.
  void setDeviceName(String name){device_name = name;}
  void setUseSleepMode(bool value){use_sleep_mode = value;}
  void setSleepMinutes(int value){sleep_minutes = value;}
  void setUseAnalogSensor(bool value){use_analog_sensor = value;}
  void setSensorClass(String value){sensor_class = value;}
  void setUseArduinoMapFunction(bool value){use_arduino_map_function = value;}
  void setAnalogMinValue(int value){analog_min_value = value;}
  void setAnalogMaxValue(int value){analog_max_value = value;}

#ifdef PIO_UNIT_TESTING
  void persistConfigForTest(){persistConfig();}
#endif
```

En la sección `private:`, junto al resto de miembros:

```cpp
  String config_token;

  void persistConfig(); //! Serializes all current members to /config.json
```

- [ ] **Step 4: Implementar `persistConfig()` en `src/manager.cpp`, extrayendo la lógica de guardado actual**

Añadir la función (por ejemplo, justo antes de `Manager::setup_wifi()`):

```cpp
void Manager::persistConfig(){
  DynamicJsonDocument json(1024);

  json["network_ip"] = network_ip;
  json["network_mask"] = network_mask;
  json["network_gateway"] = network_gateway;

  json["mqtt_server"] = mqtt_server;
  json["mqtt_port"] = mqtt_port;
  json["mqtt_user"] = mqtt_user;
  json["mqtt_password"] = mqtt_password;

  json["use_sleep_mode"] = use_sleep_mode ? "true" : "false";
  json["sleep_minutes"] = String(sleep_minutes);

  json["device_name"] = device_name;

  json["use_analog_sensor"] = use_analog_sensor ? "true" : "false";
  json["sensor_class"] = sensor_class;
  json["use_arduino_map_function"] = use_arduino_map_function ? "true" : "false";
  json["analog_min_value"] = String(analog_min_value);
  json["analog_max_value"] = String(analog_max_value);

  json["config_token"] = config_token;

  File configFile = LittleFS.open("/config.json", "w");
  if (!configFile) {
    Serial.println("[Manager] Failed to open config file for writing");
    return;
  }

  serializeJson(json, Serial);
  serializeJson(json, configFile);
  configFile.close();
}
```

Reemplazar el bloque de guardado en `Manager::setup_wifi()` (líneas 247-286 actuales, desde
`if (shouldSaveConfig) {` hasta el `}` que cierra ese bloque, sin incluir el `ESP.restart()`
final que sigue igual) por:

```cpp
  if (shouldSaveConfig) {
    Serial.println("[Manager] Saving configuration");

    network_ip = custom_network_ip.getValue();
    network_mask = custom_network_mask.getValue();
    network_gateway = custom_network_gateway.getValue();

    mqtt_server = custom_mqtt_server.getValue();
    mqtt_port = custom_mqtt_port.getValue();
    mqtt_user = custom_mqtt_username.getValue();
    mqtt_password = custom_mqtt_password.getValue();

    String sleepAux = custom_use_sleep_mode.getValue();
    sleepAux.toLowerCase();
    use_sleep_mode = sleepAux.equals("true");
    sleep_minutes = String(custom_sleep_minutes.getValue()).toInt();

    device_name = custom_device_name.getValue();

    String analogAux = custom_use_analog_sensor.getValue();
    analogAux.toLowerCase();
    use_analog_sensor = analogAux.equals("true");
    sensor_class = custom_sensor_class.getValue();
    String mapAux = custom_use_map_function.getValue();
    mapAux.toLowerCase();
    use_arduino_map_function = mapAux.equals("true");
    analog_min_value = String(custom_analog_min_value.getValue()).toInt();
    analog_max_value = String(custom_analog_max_value.getValue()).toInt();

    persistConfig();

    Serial.println("[Manager] \nRestarting...");
    ESP.restart();
    //end save
  }
```

En `Manager::setup_config_data()`, dentro del bloque `if (!json.isNull()) { ... }` (tras la
línea que lee `analog_max_value`), añadir la lectura de `config_token`:

```cpp
          config_token = (const char *)json["config_token"];
```

(La generación automática cuando falta se añade en el Task 2 — de momento solo se lee, y si
no existe queda como cadena vacía, que es el comportamiento correcto para que el Task 2 lo
detecte.)

En `Manager::Manager()` (constructor), añadir junto al resto de inicializaciones:

```cpp
  config_token = "";
```

- [ ] **Step 5: Ejecutar los tests en hardware y confirmar que pasan**

Run: `pio test -e d1_mini_lite -f test_manager`
Expected: PASS — `test_persistConfigRoundTrip` y `test_setupConfigData` en verde.

- [ ] **Step 6: Confirmar que el resto de la suite y el build de firmware siguen intactos**

Run: `pio run -e d1_mini_lite`
Expected: build sin errores (el refactor no cambia comportamiento del portal).

- [ ] **Step 7: Commit**
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

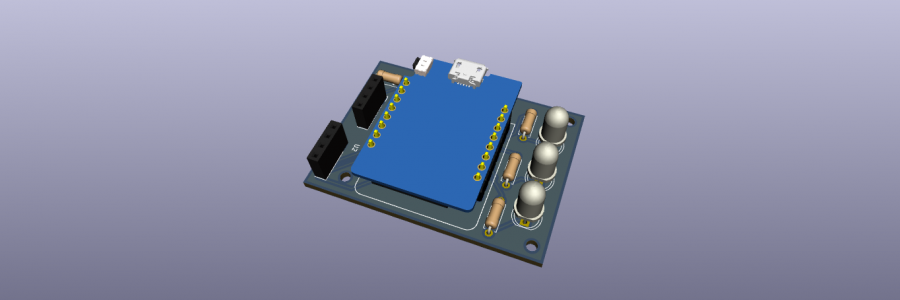
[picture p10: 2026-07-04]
docs/assets/images/meteo-home-v2.png

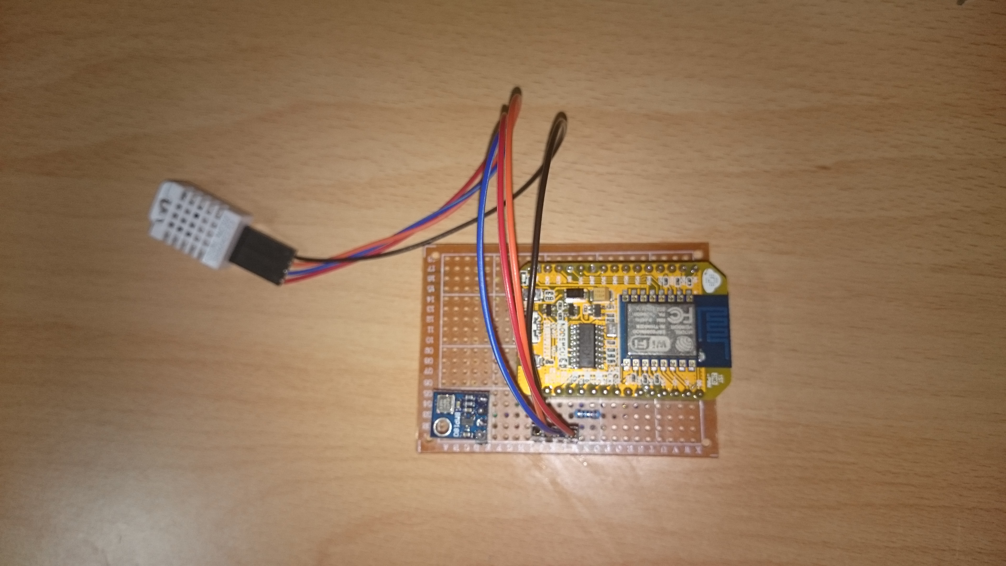
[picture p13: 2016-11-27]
docs/assets/images/prototype.JPG

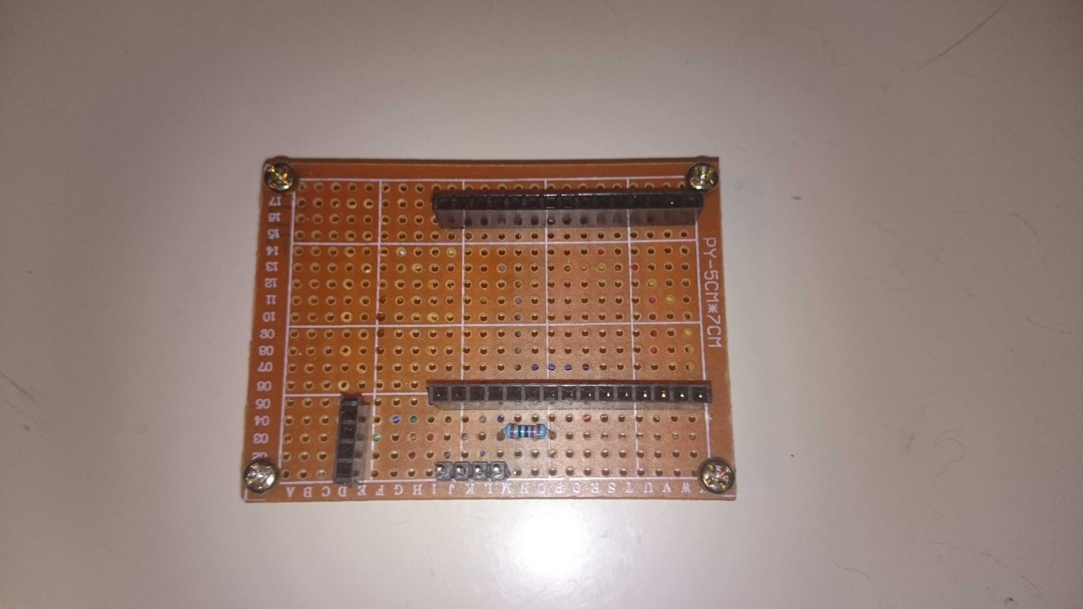
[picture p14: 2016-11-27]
docs/assets/images/perfboard.JPG

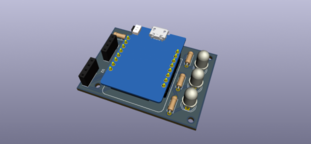
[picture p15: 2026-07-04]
docs/assets/images/meteo-home-v2-small.png

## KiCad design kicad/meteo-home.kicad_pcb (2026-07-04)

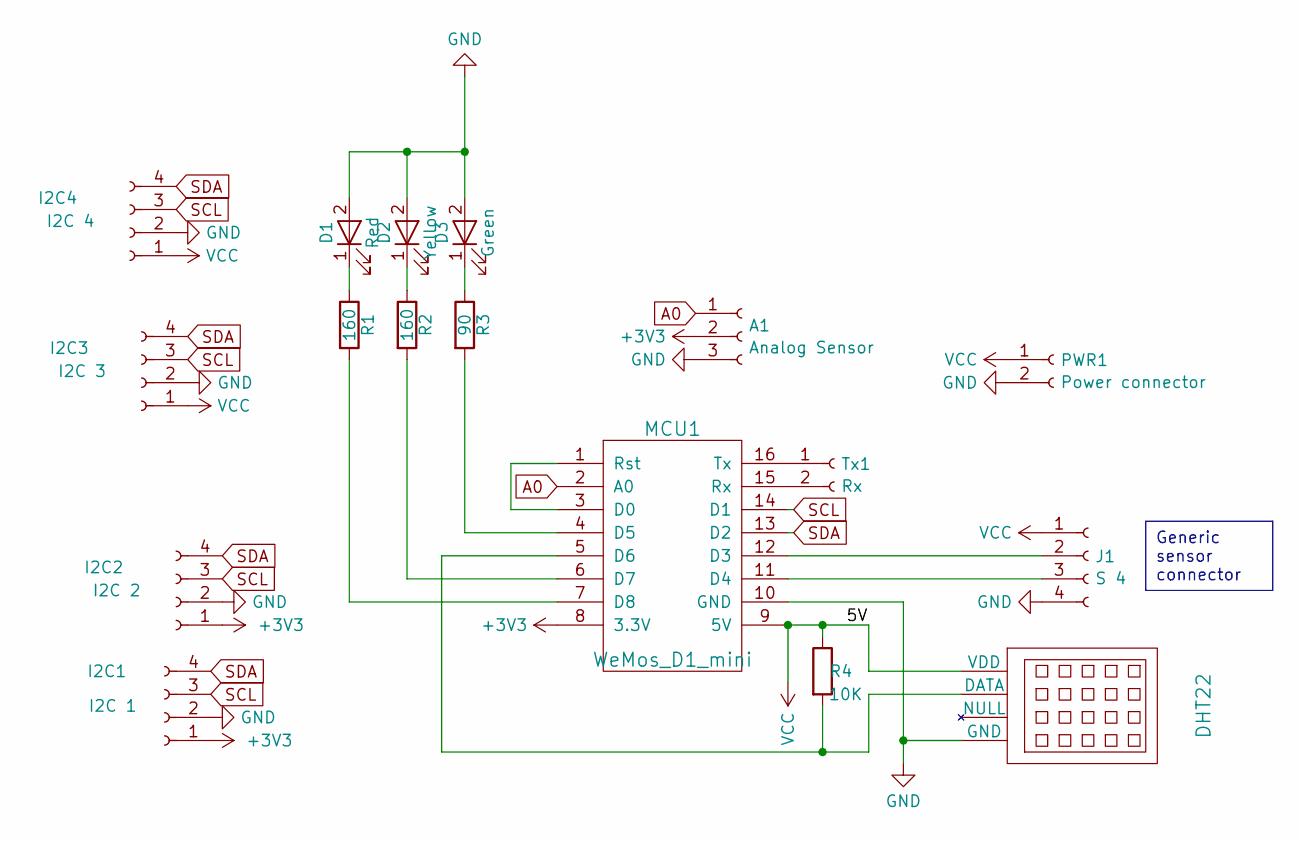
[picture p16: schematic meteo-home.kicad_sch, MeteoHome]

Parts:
A1: Analog Sensor; PinSocket_1x03_P2.54mm_Vertical
D1: Red; LED_D3.0mm
D2: Yellow; LED_D3.0mm
D3: Green; LED_D3.0mm
DHT22: DHT22_Temperature_Humidity
I2C1: I2C 1; PinSocket_1x04_P2.54mm_Vertical
I2C2: I2C 2; PinSocket_1x04_P2.54mm_Vertical
I2C3: I2C 3; PinSocket_1x04_P1.00mm_Vertical
I2C4: I2C 4; PinSocket_1x04_P1.00mm_Vertical
J1: S 4; PinSocket_1x04_P2.54mm_Vertical
MCU1: WeMos_D1_mini; WEMOS_D1_mini_light
PWR1: Power connector; Molex_SL_171971-0002_1x02_P2.54mm_Vertical
R1, R2: 160; R_Axial_DIN0204_L3.6mm_D1.6mm_P5.08mm_Horizontal
R3: 90; R_Axial_DIN0204_L3.6mm_D1.6mm_P5.08mm_Horizontal
R4: 10K; R_Axial_DIN0204_L3.6mm_D1.6mm_P5.08mm_Horizontal
Tx1: Rx; PinSocket_1x02_P2.54mm_Vertical

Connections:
+3V3: A1.2, I2C1.1, I2C2.1, MCU1.8 (3.3V)
A0: A1.1, MCU1.2 (A0)
GND: A1.3, D1.2 (A), D2.2 (A), D3.2 (A), DHT22.4 (GND), I2C1.2, I2C2.2, I2C3.2, I2C4.2, J1.4, MCU1.10 (GND), PWR1.2
unnamed: D1.1 (K), R1.1
unnamed: D2.1 (K), R2.1
unnamed: D3.1 (K), R3.1
unnamed: DHT22.2 (DATA), MCU1.5 (D6), R4.2
unnamed: J1.2, MCU1.12 (D3)
unnamed: J1.3, MCU1.11 (D4)
unnamed: MCU1.1 (Rst), MCU1.3 (D0)
unnamed: MCU1.4 (D5), R3.2
unnamed: MCU1.6 (D7), R2.2
unnamed: MCU1.7 (D8), R1.2
unnamed: MCU1.15 (Rx), Tx1.2
unnamed: MCU1.16 (Tx), Tx1.1
SCL: I2C1.3, I2C2.3, I2C3.3, I2C4.3, MCU1.14 (D1)
SDA: I2C1.4, I2C2.4, I2C3.4, I2C4.4, MCU1.13 (D2)
VCC: DHT22.1 (VDD), I2C3.1, I2C4.1, J1.1, MCU1.9 (5V), PWR1.1, R4.1

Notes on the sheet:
Generic sensor connector

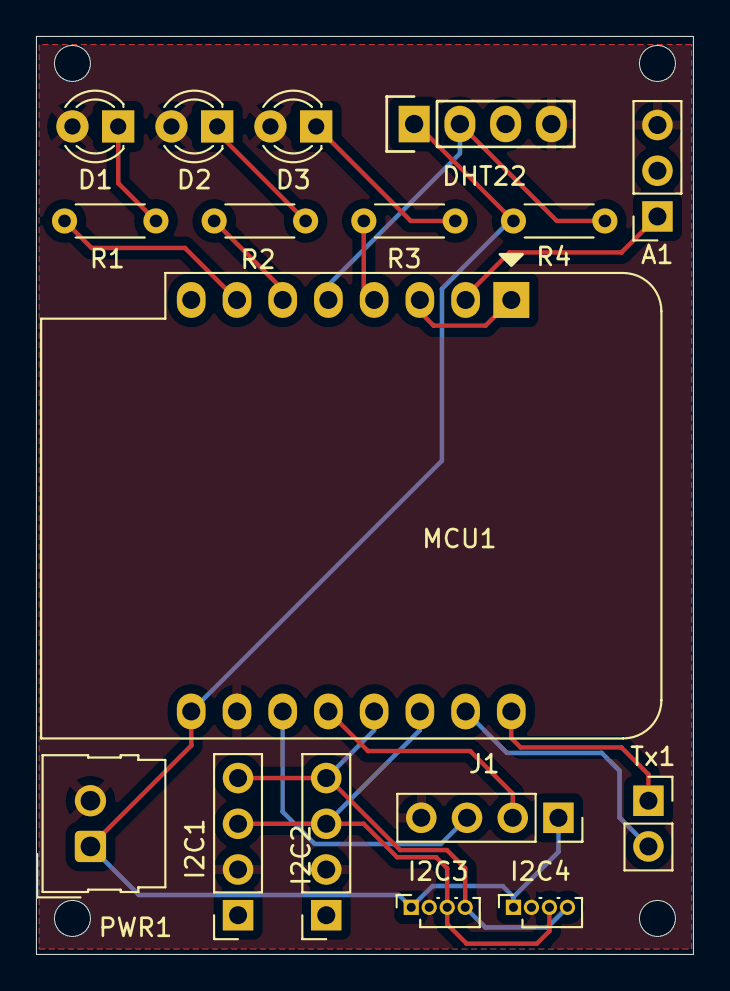
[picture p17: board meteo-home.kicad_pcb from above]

Board: 2 copper layers, 36.5 x 51.0 mm, 17 parts (0 on the bottom side), 18 nets.

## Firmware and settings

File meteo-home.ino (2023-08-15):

/*
  Copyright 2022 meteo-home

  Licensed under the Apache License, Version 2.0 (the "License");
  you may not use this file except in compliance with the License.
  You may obtain a copy of the License at

    http://www.apache.org/licenses/LICENSE-2.0

  Unless required by applicable law or agreed to in writing, software
  distributed under the License is distributed on an "AS IS" BASIS,
  WITHOUT WARRANTIES OR CONDITIONS OF ANY KIND, either express or implied.
  See the License for the specific language governing permissions and
  limitations under the License.
*/

#include <ESP8266WiFi.h>
#include <Wire.h>
#include <Adafruit_BMP085.h>
#include <PubSubClient.h>
#include <DHT.h>
#include "manager.h"

//Temperature sensor settings
#define DHTPIN 12 // what digital pin we're connected to
#define DHTTYPE DHT22 // DHT 22  (AM2302), AM2321

// LEDs pins
#define GREEN_PIN 14
#define YELLOW_PIN 13
#define RED_PIN 15

//Timeout connection for wifi or mqtt server
#define CONNECTION_TIMEOUT 20000 //Timeout for connections. The idea is to prevent for continuous conection tries. This would cause battery drain

bool bmpSensorReady;
DHT dht(DHTPIN, DHTTYPE); //! Initializes the DHT sensor.
Adafruit_BMP085 bmp; //1 Bmp sensor object
Manager manager;  //! Portal and wific connection manager
//MQTT client
WiFiClient espClient;
PubSubClient client(espClient);

//Global variables for sensor data
float temperature = 0;
float device_temperature = 0;
float humidity = 0;
float heatindex = 0;
float pressure = 0;

long t_elapsed;

bool useSleepMode=false;
uint32_t first_boot_done=0; //! Used with deepsleep mode. Send the discovery messages only in the first boot and not after sleeping.


void setup() {
  // Check if this is the first boot (Usefull if using deep sleep mode)
  ESP.rtcUserMemoryRead(0,&first_boot_done,sizeof(first_boot_done)); // Read from persistent RAM memory

  //Serial port speed
  t_elapsed = millis();
  Serial.begin(115200);
  Serial.println("Confifuring device...");

  // Configuration of LED pins
  pinMode(GREEN_PIN, OUTPUT);
  pinMode(YELLOW_PIN, OUTPUT);
  pinMode(RED_PIN, OUTPUT);

  // Turn on the LEDs to show the device is configureing. In sleep mode, we don't want to use the LEDs everytime the device wakes up
  if (first_boot_done != 1){  
    digitalWrite(RED_PIN, HIGH);
    digitalWrite(YELLOW_PIN, HIGH);
    digitalWrite(GREEN_PIN, HIGH);

    delay(1000); // Just one second to show that the process has started
    
    digitalWrite(RED_PIN, LOW);
    digitalWrite(YELLOW_PIN, LOW);
    digitalWrite(GREEN_PIN, LOW);
  }

  // WiFi setup
  manager.setup_config_data();
  manager.setup_wifi();
  //DHT sensor for humidity and temperature
  dht.begin();
  //BMP180 sensor for pressure
  bmpSensorReady=bmp.begin();
  //Setup mqtt
  IPAddress addr;
  addr.fromString(manager.mqttServer());
  client.setServer(addr, atoi(manager.mqttPort().c_str())); 

  if (!client.connected()) {
    reconnect();
  }
  client.loop();

  if (first_boot_done != 1){
    first_boot_done = 1;
    ESP.rtcUserMemoryWrite(0,&first_boot_done,sizeof(first_boot_done)); // Write to persistent RAM memory
    char buf[256];
    
    Serial.println("Sending Home Assistant discovery messages.");

    String message = manager.getDiscoveryMsg(manager.dhtTemperatureTopic(), temperature_sensor);
    message.toCharArray(buf, message.length() + 1);
    if (client.beginPublish (manager.dhtTemperatureDiscoveryTopic().c_str(), message.length(), true)) {
      for (int i = 0; i <= message.length() + 1; i++) {
        client.write(buf[i]);
      }
      client.endPublish();
    } else {
      Serial.println("Error sending temperature discovery message");
    }

    // Not sure why but I have to disconnect and connect again to make work the second publish
    client.disconnect();
    reconnect();
    message = manager.getDiscoveryMsg(manager.dhtHumidityTopic(), humidity_sensor);
    message.toCharArray(buf, message.length() + 1);
    if (client.beginPublish (manager.dhtHumidityDiscoveryTopic().c_str(), message.length(), true)) {
      for (int i = 0; i <= message.length() + 1; i++) {
        client.write(buf[i]);
      }
      client.endPublish();
    } else {
      Serial.println("Error sending humidity discovery message");
    }

    client.disconnect();
  }

  manager.useSleepMode().toLowerCase();
  if (manager.useSleepMode().equals("true")){
    useSleepMode = true;
  } 

  if (!bmpSensorReady){
    digitalWrite(RED_PIN, HIGH);    
  }
  
  digitalWrite(GREEN_PIN, HIGH);  
  Serial.println("Configured!!");
}


void reconnect() {
  // Loop until we're reconnected
  long t1 = millis();
  while (!client.connected() && (millis() - t1 < CONNECTION_TIMEOUT)) {
    // Attempt to connect
    String clientName("ESPClient-");
    clientName.concat(ESP.getChipId());
    Serial.print("Attempting MQTT connection... ");
    Serial.println(clientName.c_str());
    if (client.connect(clientName.c_str())) {
      Serial.println("Connected to mqtt");
    } else {
      digitalWrite(RED_PIN, LOW);
      digitalWrite(YELLOW_PIN, LOW);
      digitalWrite(GREEN_PIN, LOW);
      Serial.print("failed, rc=");
      Serial.println(client.state());
      Serial.println(manager.mqttServer());
      Serial.println(manager.mqttPort().c_str());
      Serial.println(" trying again in 5 seconds");
      // Wait 5 seconds before retrying
      delay(2500);
      digitalWrite(YELLOW_PIN, HIGH);
      delay(2500);
      digitalWrite(YELLOW_PIN, LOW);
    }
  }
  digitalWrite(YELLOW_PIN, LOW);
}

void readDHT22(){  
  //read dht22 value
  temperature = dht.readTemperature();    
  humidity = dht.readHumidity();
  heatindex = dht.computeHeatIndex(temperature, humidity, false);
     
  Serial.print(temperature);
  Serial.print(" ");
  Serial.print(humidity);
  Serial.print(" ");
  Serial.println(heatindex);
}

/** 
 *  Reads the pressure unsing the BMP180 but also the temperature which is used as the interenal device temperature reference
 */
void readBMP180(){  
  //bmp180
  if (bmpSensorReady){
    device_temperature = bmp.readTemperature(); 
    pressure = bmp.readPressure()/100.0; //Dividing by 100 we get The pressure in Bars
    Serial.print("Pressure is ");
    Serial.println(pressure);
    Serial.print("Internal temp is ");
    Serial.println(device_temperature);
  }
}

void loop() {  
  Serial.print("Starting...");
  if (!client.connected()) {
    reconnect();
  }  
  client.loop();

  readDHT22();
  if (isnan(temperature) || isnan(humidity)){
    Serial.println("Error reading DHT22 values");    
  }else {
    client.publish(manager.dhtTemperatureTopic().c_str(), String(temperature).c_str(), true);
    Serial.print(String(manager.dhtTemperatureTopic().c_str()));
    Serial.println(String(temperature).c_str());
    delay(50);
    client.publish(manager.dhtHumidityTopic().c_str(), String(humidity).c_str(), true);
    Serial.print(String(manager.dhtHumidityTopic().c_str()));
    Serial.println(String(humidity).c_str());
    delay(50);
    client.publish(manager.dhtHeatindexTopic().c_str(), String(heatindex).c_str(), true);
    Serial.print(String(manager.dhtHeatindexTopic().c_str()));
    Serial.println(String(heatindex).c_str());
    delay(50);
  }
  readBMP180();
  if (isnan(pressure) || pressure== 0 || isnan(device_temperature)){
    Serial.println("Error reading BMP180 values");    
  }else {
    client.publish(manager.bmpPressureTopic().c_str(), String(pressure).c_str(), true); 
    Serial.print(String(manager.bmpPressureTopic().c_str()));
    Serial.println(String(pressure).c_str());
    delay(50);
    client.publish(manager.bmpTemperatureTopic().c_str(), String(device_temperature).c_str(), true); 
    Serial.print(String(manager.bmpTemperatureTopic().c_str()));
    Serial.println(String(device_temperature).c_str());
    delay(50);
  }


  if (useSleepMode){
    Serial.print("Going to sleep after ");
    Serial.println((millis()-t_elapsed)/1000);
    ESP.deepSleep(DEEP_SLEEP_TIME * 1000000);
  }else{
    delay(DEEP_SLEEP_TIME * 1000);
  }
}

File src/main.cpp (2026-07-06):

/*
  Copyright 2022 meteo-home

  Licensed under the Apache License, Version 2.0 (the "License");
  you may not use this file except in compliance with the License.
  You may obtain a copy of the License at

    http://www.apache.org/licenses/LICENSE-2.0

  Unless required by applicable law or agreed to in writing, software
  distributed under the License is distributed on an "AS IS" BASIS,
  WITHOUT WARRANTIES OR CONDITIONS OF ANY KIND, either express or implied.
  See the License for the specific language governing permissions and
  limitations under the License.
*/
#ifndef PIO_UNIT_TESTING

#include <ESP8266WiFi.h>
#include <ArduinoOTA.h>
#include <Wire.h>
#include <PubSubClient.h>
#include "connection.hpp"
#include "meteoboard.hpp"
#include "mhdht.hpp"
#include "mhanalog.hpp"
#include "mhbmp.hpp"
#include "mhsgp30.hpp"
#include "mhaht20.hpp"
#include "mhvoltage.hpp"
#include "manager.hpp"
#include "leds.hpp"

//Temperature sensor settings
#define DHTPIN 12 
#define DHTTYPE DHT22 // DHT 22  (AM2302), AM2321

#define RTC_FIRST_USABLE_ADDRESS 65 // Must be >64 as explained here https://github.com/esp8266/Arduino/blob/24c41524dc56c683d8926671bdd639d7411f2815/cores/esp8266/Esp.cpp#L154

//Timeout connection for wifi or mqtt server
#define CONNECTION_TIMEOUT 20000 //Timeout for connections. The idea is to prevent for continuous conection tries. This would cause battery drain

//OTA update window
#define OTA_WAIT_TIME 30000 //Time in milliseconds to wait for OTA updates at startup

//MQTT client
WiFiClient espClient;
PubSubClient client(espClient);

Manager manager;  //! Portal and wific connection manager
MeteoBoard board(&manager, &client);
MHDHT dht(&board, &manager,DHTPIN, DHTTYPE); //! Initializes the DHT sensor.
MHBMP bmp(&board, &manager); //! Bmp sensor object
MHAHT20 aht20(&board, &manager); //! Bmp sensor object
Leds leds; //! To mange the three LEDs
MHSGP30 sgp30(&board, &manager,&leds); //! Air quality sensor. Leds is a dependency for showing the air quality state
MHVoltage voltage(&board, &manager);
MHAnalog analog(&board, &manager); //! Analog sensor attached to the board

long t_elapsed;

bool useSleepMode=false;
bool useAnalogSensor=true; //! In ESP8266 we cannot use an analog sensor and meassure VCC input at the same time. This variable is used to block the VCC mode.
uint32_t first_boot_done=0; //! Used with deepsleep mode. Send the discovery messages only in the first boot and not after sleeping.

typedef struct {
  bool useAnalogSensor=true;
  uint32_t first_boot_done=0 ;
} rtcStore;

int get_ADC(){
  rtcStore rtcMem; 
  system_rtc_mem_read(RTC_FIRST_USABLE_ADDRESS, &rtcMem, sizeof(rtcMem));
  first_boot_done=rtcMem.first_boot_done;
  useAnalogSensor=rtcMem.useAnalogSensor;
  
  //! When is booting for the first time after pluging the power wire, we assume the memory is filled with 0s. If we press reset the memory will keep its values but
  //! is prefearable to let ADC_TOUT when first_boot_done is 0 
  if (first_boot_done==0){ 
    return ADC_TOUT;
  }
  else if (useAnalogSensor){
    return ADC_TOUT;
  }else{
    return ADC_VCC;
  }
}

ADC_MODE(get_ADC()); // Normally ADC_MODE(ADC_VCC) is used but we want to select between VCC and TOUT (https://arduino-esp8266.readthedocs.io/en/latest/libraries.html) Add the following line to the top of your sketch to use getVcc:


void setup() {
  // Check if this is the first boot (Usefull if using deep sleep mode)
  // get_ADC() (the ADC_MODE static init) already populated first_boot_done and
  // useAnalogSensor from RTC memory, so capture cold boot (power-on) vs wake from
  // deep sleep now, before first_boot_done is overwritten below.
  bool firstBoot = (first_boot_done != 1);

  rtcStore rtcMem;
  system_rtc_mem_read(RTC_FIRST_USABLE_ADDRESS, &rtcMem, sizeof(rtcMem)); // Read from persistent RAM memory
  first_boot_done=rtcMem.first_boot_done;

  //Serial port speed
  t_elapsed = millis();
  Serial.begin(9600);
  Serial.println("[Main] Confifuring device...");

  // PubSubClient's default MQTT_MAX_PACKET_SIZE (256 bytes, topic+payload+header combined)
  // is too small for a full config/set command (token + all 8 fields, as sent by
  // tools/remote-config.html): worst case device_name(40)+sensor_class(20) needs ~350
  // bytes. Oversized incoming PUBLISH packets are silently dropped by PubSubClient
  // (callback never fires, no error), so this must be raised before any MQTT connection.
  client.setBufferSize(512);

  // WiFi setup
  manager.setup_config_data();
  manager.setup_wifi();
  
  //! At this poing we need to know if the analog sensor was selected by the user
  useAnalogSensor=manager.useAnalogSensor();

  leds.begin();

  // Turn on the LEDs to show the device is configureing. In sleep mode, we don't want to use the LEDs everytime the device wakes up
  if (first_boot_done != 1){  
    leds.setLEDs(HIGH,HIGH,HIGH);
    delay(1000); // Just one second to show that the process has started    
    leds.setLEDs(LOW,LOW,LOW);

    rtcMem.first_boot_done=1; //! Warnig! We write 1 to rtcmem but we still need the global first_boot_done be 0
    rtcMem.useAnalogSensor=useAnalogSensor;
    system_rtc_mem_write(RTC_FIRST_USABLE_ADDRESS, &rtcMem, sizeof(rtcMem)); // Write to persistent RAM memory
  }

  Wire.begin();

  //ESP board
  board.begin();
  
  //DHT sensor for humidity and temperature
  if (dht.begin()){
    board.addSensor(&dht);
  }
  //BMP180 sensor for pressure  
  if (bmp.begin()){
    board.addSensor(&bmp);
  }
  //SGP30 sensor for air quality
  if (sgp30.begin()){
    board.addSensor(&sgp30);
  }
  //AHT20 sensor for humidity and temperature
  if (aht20.begin()){
    board.addSensor(&aht20);
  }

  if (useAnalogSensor){ //! If we use the analog input we will avoid to meassure the VCC input.
    //Analog sensor
    if (analog.begin()){
      board.addSensor(&analog);
    }
  }
  else{
    //Builtin voltage sensor
    if (voltage.begin()){
      board.addSensor(&voltage);
    }
  }

  //! Send Home Assistant autodiscovery only on a cold boot, not after waking from deep sleep
  if (first_boot_done != 1){
    first_boot_done = 1;
    board.autodiscover();
  }
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

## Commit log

2016-11-29 Bread board picture
2016-12-08 code refactoring
    [meteo-home.fzz]
2016-12-08 pin changed
    [meteo-home.fzz]
2017-07-12 Server IP using a string caused an error
    [meteo-home.ino]
2017-08-10 DCHP removed. Now requires manual configuration but this makes the device more efficent
2017-08-10 Bugfix: exception fixed when the BMP180 was not connected
    [meteo-home.ino]
2020-10-12 Trying to fix a wrong configuration adter setting up all the required values
    [manager.cpp, meteo-home.ino]
2020-10-12 First complete design of the PCB
    [meteo-home.kicad_pcb, meteo-home.sch]
2020-10-12 Gerber files
    [meteo-home-B_Cu.gbr, meteo-home-B_Mask.gbr, meteo-home-B_Paste.gbr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]
2022-09-02 Better connection process control
    [meteo-home.kicad_pcb, meteo-home.sch]
2022-09-02 refactoring: now using a newer (which incompatible with the previous version) ArduinoJSON library
    [manager.cpp, meteo-home.ino]
2022-09-02 fix: avoid exceptions when sensors are not working and not giving values
    [meteo-home.ino]
2022-09-02 fix: hostname is correctly assigned. Format is Meteo-home_MACADDRESS
    [manager.cpp]
2022-09-02 fix: board updated to the last one used in co2-detector
    [meteo-home.kicad_pcb, meteo-home.sch]
2022-09-02 fix: allow deep sleep conecting RST and D0
    [meteo-home.kicad_pcb, meteo-home.sch]
2022-09-07 fix: device class removed as it is not parameterized
    [manager.cpp]
2022-09-07 fix: topic name corrected
    [meteo-home.ino]
2022-09-18 feat: better usage of LEDs during the setup function
2022-12-10 feat: BMP180 is detected if is connected to the SGP30 header. This requires to to change the wiring between SCL and SDA. Currently only prints the information trough the serial monitor
2023-08-10 feat: discovery parameters to identify better all sensors in Home Assistant and make them available to statistics
2023-08-12 fix: better management of messages and correction of some bpm180 parameters
    [manager.cpp, meteo-home.ino]
2023-08-15 feat: turn on the LEDs during the first boot when using deep sleep mode
2023-08-15 feat: adding labels to the sensors holes
    [meteo-home.kicad_pcb]
2023-08-16 feat: simplified configuration form. MQTT topics are generated from the device name parameter.
2023-08-19 refactor: separete classes for the different sensors conected
2023-08-21 fix: fixes on BMP180 sensor
    [manager.cpp, mhbmp.cpp]
2023-08-22 refactor: sensor topics are not stored in the json configuration file anymore. The properties and functions related to them have been moved to the appropriate sensor class
2023-08-22 fix: do not send discovery messages for DHT if it is not available
    [manager.cpp]
2023-08-23 refactor: better format of output messages and reduced number of printings to Serial
2023-09-01 feat: new class for managing the ESP board. Currently is similar to sensor classes but it is expected to ibclude differente methods and properties in the future
2023-09-04 refactor: using an array of sensort objects to simplify and reduce the code. Sensor objects are directly using the mqtt client object
2023-09-05 refactor: normalizing output messages for DHT and BMP sensors
2023-09-05 refactor: discovery messages are sent by the corresponding sensor object
2023-09-29 refactor: using standard vector to store pointers to the different sensor objects
2023-09-30 fix: missing manager include file recovered
    [main.cpp, manager.cpp]
2023-09-30 refactor: new LED class to manage all red, green and yellow, the LEDs
2023-10-01 refactor: SGP30 LEDs dependency injection
2023-10-01 refactor: reducing the number of prints
2023-10-20 refactor: sensor discovery messages and values publication are moved to the board class. Now a board has a vector of sensors
2023-11-03 fix: base line is read and saved again
    [mhsgp30.cpp]
2023-11-11 refactor: SPIFFS replaced by LittleFS
    [manager.cpp, meteoboard.cpp, mhsgp30.cpp]
2023-12-09 fix: refill before sending to factory
    [meteo-home.kicad_pcb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]
2023-12-09 feat: reset after configuration is saved. This avoids WiFiManager to connect using DHCP (this only happened fater saving the config data)
    [manager.cpp]
2024-08-21 feat: aht20 humidity and temperatures sensor is now supported
2024-08-25 Fix: corrected values for the discovery message of the AHT20 humidity sensor
    [mhaht20.cpp]
2024-08-25 feat: added a message in case of error in message (end) publishing
    [meteoboard.cpp]
2024-08-25 feat: new components added (RX/TX)
    [meteo-home.kicad_sch, meteo-home.sch]
2024-09-08 Feat: i2c connectors pins and disposition changed
    [meteo-home.kicad_pcb, meteo-home.kicad_sch]
2024-09-09 Fix: connectors relocation
    [meteo-home.kicad_pcb, meteo-home.kicad_sch]
2024-09-24 Feat: last chenges. Sent to factory
    [meteo-home-B_Cu.gbl, meteo-home-B_Cu.gbr, meteo-home-B_Mask.gbr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]
2024-10-05 feat: analaog sensor reading. Testing with a moisture sensor
2024-10-06 fix: when first booting after pluging in the porwe cable, analogRead was reading VCC
    [main.cpp, mhaht20.cpp, mhanalog.cpp]
2024-10-10 feat: configuration form improvementes. Dinamically showing and hidding elements. More parameters available: analog sensor can use or not the Arduino map function
2024-10-12 feat: sensor class is configured base on the deviceclass parameter requested in the web form ;
2024-10-17 fix: exception throw removed
    [mhanalog.cpp]
2024-10-21 fix: wrong topic name corrected
    [mhanalog.cpp]
2024-10-22 fix: wrong topic path corrected
    [mhanalog.cpp]
2024-10-24 doc: more information about sensors and LEDs
2024-10-30 fix: static IP connection is woking through WifiManager
    [main.cpp, manager.cpp]
2026-02-18 fix: wrong temperature character
    [mhaht20.cpp, mhbmp.cpp]
2026-03-27 feat: add OTA (Over-The-Air) update support
    - Add ArduinoOTA integration with hostname "meteo-home"
    - Add 30-second OTA wait window at startup to allow firmware uploads
    - Add OTA event handlers for progress, errors, and completion logging
    - Add new PlatformIO environment 'd1_mini_lite_ota' for OTA uploads
    - Handle OTA in main loop for updates outside the startup window
    Amp-Thread-ID: https://ampcode.com/threads/T-019d30ba-f078-76fe-abf6-7dc0b423f4f2
    [main.cpp]
2026-03-27 feat: improve MQTT reliability and Home Assistant integration
    - Subscribe to homeassistant/status topic and resend discovery messages
    when Home Assistant restarts (via MQTT callback)
    - Move autodiscover() call outside first_boot_done check so discovery
    runs on every boot cycle
    - Add expires_after (300s) to sensor discovery messages
    - Simplify sendDiscoveryMessage using client->print() and keep
    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
2026-03-28 feat: add MQTT availability topic and improve non-sleep loop
    - Configure MQTT Last Will and Testament (LWT) with "offline" status
    and publish "online" on connect via "meteohome/status" topic
    - Replace discovery exp_aft with availability object referencing
    the new availability topic
    - In non-sleep mode, replace blocking delay with an active loop that
    processes MQTT messages and OTA updates
    - Disconnect MQTT client before entering deep sleep
    Amp-Thread-ID: https://ampcode.com/threads/T-019d35aa-7765-7044-baf7-7a71cbd9b125
    [main.cpp, meteoboard.cpp]
2026-06-27 feat: mark sensors unavailable in HA when device stops reporting
    Add expire_after (twice the publish interval, DEEP_SLEEP_TIME * 2) plus
    explicit online/offline availability payloads to the MQTT discovery
    payload. Without expire_after, deep sleep closes the MQTT connection
    gracefully (no LWT) and Home Assistant kept showing the last retained
    value indefinitely instead of marking the sensor unavailable.
    Update discovery unit tests to match the new payload.
2026-06-27 feat: derive OTA and WiFi hostname from device name
    Build the OTA hostname and WiFi STA hostname from the configured device
    name ("meteo-<deviceName>", lowercased, spaces replaced by dashes)
    instead of a fixed "meteo-home" / MAC-based name, so each device is
    addressable by a unique, meaningful mDNS hostname.
    [main.cpp, manager.cpp]
2026-06-27 feat: use per-device MQTT availability topic
    Derive the MQTT availability/LWT topic from the device name
    ("meteohome/<deviceName>/status") via a new Manager::availabilityTopic()
    helper, used by both the LWT registration and the discovery payload.
    Previously every device shared a fixed "meteohome/status", so one device
    going offline marked all of them unavailable in Home Assistant.
    Remove the MQTT_AVAILABILITY_TOPIC macro and update discovery tests.
    [meteoboard.cpp]
2026-06-27 feat: skip OTA wait window on deep sleep wake to save battery
    In deep sleep mode the 30s OTA wait now runs only on a cold boot
    (power-on), and is skipped on every wake from deep sleep, avoiding
    unnecessary battery drain on solar/battery-powered devices. Non-sleep
    mode keeps the OTA window on every boot as before.
    The cold-boot state is captured before first_boot_done is overwritten.
    To OTA-update a sleeping device, power-cycle it to open the window.
    [main.cpp]
2026-06-27 feat: re-evaluate sensor health each cycle so HA marks failed sensors unavailable
    available() now performs a runtime liveness check instead of returning a
    flag set once at begin():
    - BMP180, SGP30, AHT20: re-probe the sensor on the I2C bus.
    - Voltage: validate the supply reading is within a plausible range.
    - DHT22: take a fresh measurement and validate it (NaN check).
    When a sensor fails at runtime, available() returns false, processSensors()
    skips its read(), the value stops being published, and Home Assistant marks
    that sensor unavailable via expire_after while the rest of the device keeps
    working.
    Also clean up the DHT22 path: drop the tangled values_read state machine
    (which could pu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
    [mhaht20.cpp, mhbmp.cpp, mhsgp30.cpp]
2026-07-03 fix: bound WiFi connection retries so a weak battery can recover
    The outer WiFi connect loop in setup_wifi() was an infinite
    `while (WiFi.status() != WL_CONNECTED)`, which made the following
    deep-sleep-on-failure guard unreachable dead code. On solar/battery
    setups a depleted cell that cannot complete a WiFi connection kept the
    radio on at ~70mA forever, so the panel could never recover the cell and
    the device stayed latched awake (only a physical power-cycle fixed it).
    Cap attempts at WIFI_MAX_CONNECTION_RETRIES so the loop exits and the
    existing deep sleep runs, letting the device idle at ~20uA and giving the
    solar panel a chance to recharge across cycles.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
    [manager.cpp]
2026-07-04 fix: repair broken merge conflict resolution in main/manager/meteosensor
    The develop merge left main.cpp, manager.cpp and meteosensor.cpp in a
    non-compiling state: a missing if-header before the analog/voltage sensor
    block, a lost board.autodiscover() call, a lost ESP.deepSleep() in the sleep
    branch, an unbalanced brace in the WiFi connect block, and expire_after/loop
    timing still referencing the now-removed DEEP_SLEEP_TIME define.
    Re-resolve using manager.sleepMinutes() (from the WiFiManager portal) as the
    single source of truth for sleep duration, restore the lost autodiscover()
    and deepSleep() calls, and rebuild the WiFi connect block on master's bounded-
    retry approach with develop's st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
    [main.cpp, manager.cpp]
2026-07-05 chore: upgrade sym-lib-table to KiCad 7 format
    KiCad rewrote the legacy symbol library table when the project was opened
    locally, adding the version marker and a cache library entry.
2026-07-05 feat: auto-generate and display a per-device remote config token
    - Implement Manager::generateToken() to create 32-char hex tokens via secureRandom()
    - Auto-generate token in setup_config_data() when config.json lacks one
    - Persist token to config.json on first generation
    - Display read-only token in WiFiManager captive portal under "Device parameters"
    - Add test_configTokenGeneratedWhenMissing() to verify token generation and persistence
2026-07-05 fix: capture MQTT topics before device_name mutation in handleConfigCommand
    The final whole-branch review found that handleConfigCommand() read
    manager->configSetTopic()/configResultTopic() after calling
    applyRemoteConfig(), which can mutate device_name as a side effect. A
    payload that renamed the device caused the result to publish to the new
    device's topic and left the retained command (containing the plaintext
    config_token) uncleared on the old device's topic.
    [meteoboard.cpp]
2026-07-05 fix: use bounded deserializeJson to avoid buffer overread in setup_config_data
    The config-loading buffer is allocated with exactly the file's byte size
    and no null terminator, then was passed to the unbounded char* overload
    of deserializeJson, which reads until it finds a \0 byte. With no
    terminator in the allocation, this reads past the buffer into adjacent
    heap memory (undefined behavior), observed on-device as a LoadProhibited
    crash after persistConfig() started writing a larger config.json
    (including the new config_token field). Switching to the explicit-length
    overload (deserializeJson(json, buf.get(), size)) parses exactly the
    bytes read, regardless of what follows in memory.
    Co-Autho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
    [manager.cpp]
2026-07-05 fix: resend discovery on remote config apply to refresh expire_after
    sleep_minutes affects each sensor's expire_after in its retained discovery
    message, but discovery only normally resends on a cold boot (RTC-memory
    gated). ESP.restart() after a successful remote config change is a software
    reset that preserves that RTC flag, so the stale expire_after (and any other
    discovery field derived from now-changed config) stuck around until the next
    power cycle.
    [meteoboard.cpp]
2026-07-05 feat: add device section, config/state read-back and config form
2026-07-05 feat: add apply/result flow and per-device token persistence
2026-07-06 fix: increase PubSubClient buffer to fit full config/set payload
    PubSubClient's default MQTT_MAX_PACKET_SIZE (256 bytes) silently drops any
    incoming PUBLISH packet whose encoded size exceeds it (readPacket sets
    len=0, the callback never fires, no error is raised). The remote-config
    HTML page always sends the full 8-field + token payload atomically, which
    comfortably exceeds 256 bytes and was being dropped before reaching
    handleConfigCommand — matching the reported symptom (message stays
    retained, never processed, no config/result reply).
    [main.cpp]
2026-07-06 fix: drain MQTT backlog after subscribing to avoid missing retained config/set in deep-sleep
    PubSubClient::loop() processes at most one incoming packet per call. In
    deep-sleep mode, connectToMQTT() previously relied on incidental loop()
    calls from each sensor read to drain the two SUBACKs (homeassistant/status,
    config/set) plus a possible retained config/set delivery — with few or
    failing sensors and a brief awake window, there weren't enough calls to
    receive the message before the device went back to sleep. Awake
    (non-sleep) mode was unaffected: it calls loop() every 100ms for the whole
    interval, so it always had enough opportunities.
    [meteoboard.cpp]
